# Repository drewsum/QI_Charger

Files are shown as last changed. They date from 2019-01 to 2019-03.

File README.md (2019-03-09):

# QI_Charger

A DIY QI Wireless Phone Charger with Digital Monitoring, OLED Display, and USB Virtual COM Port

Made with KiCad 5.0.2

Requires drewsum's 'KiCad_Custom_Libraries' git repository for custom symbols and footprints

Microcontroller U503 is programmed via header J401 using PIC KIT 3, with firmware located at sfw/U503_Firmware/QI_Monitor.X

Built with Microchip compiler XC8 V1.45, IDE MPLAB V5.15

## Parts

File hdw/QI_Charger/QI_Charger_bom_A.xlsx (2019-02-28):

References | Value | Quantity Per PCB | Digi-Key PN
C201 C204 C205 C303 C304 C401 C402 C501 C502 C503 C506 C601 C602 C609 C613 C701 C807 C808 C901 C902 C1001 C1002 C1003 C1004 C1005 C1007 C1008 C1011 C1101 C1102 C1103 C1104 C1105 C1106 C1107 C1108 C1109 C1201 C1202 C1203 C1301 C1309 C1311 C1314 C1316 C1401 C1403 C1404 | 0.1uF | 48 | 311-1344-1-ND
C209 C1323 | 100uF | 2 | 718-1102-1-ND
C202 C206 C302 C305 C504 C507 C603 C604 C607 C608 C610 C612 C614 C616 C702 C801 C802 C805 C806 C1302 C1310 C1312 C1319 C1402 | 10nF | 24 | 1276-1921-1-ND
C301 | 10uF | 1 | 1276-7031-1-ND
C203 C207 C208 C306 C505 C508 C605 C606 C611 C615 C703 C803 C804 C1303 C1304 C1306 C1317 C1405 | 1nF | 18 | 1276-1018-1-ND
C704 | 1uF | 1 | 490-1695-1-ND
C1305 | 2.2pF | 1 | 1276-1281-1-ND
C1318 C1322 | 22nF | 2 | 399-1280-1-ND
C307 C308 C1307 C1308 | 22uF | 4 | 1276-3148-1-ND
C1006 | 4.7uF | 1 | 1276-2972-1-ND
C1009 C1010 | 47pF | 2 | 478-1171-1-ND
C1313 C1315 | 6.8nF | 2 | 399-9121-1-ND
C1320 C1321 | 82nF | 2 | 478-10362-1-ND
D201 | 24V | 1 | SMAJ24CALFCT-ND
D1001 D1105 D1107 D1108 D1109 | Green | 5 | 160-1446-1-ND
D1301 | MBR0530 | 1 | MBR0530T1GOSCT-ND
D1101 D1102 D1103 D1104 D1106 | Red | 5 | 160-1447-1-ND
D1002 | Yellow | 1 | 160-1448-1-ND
DOC701 | 0x3C | 1
DOC1202 | 0x4C | 1
DOC1201 | 0x4D | 1
DOC1203 | 0x4F | 1
DOC1001 | COM_Port_Settings | 1
DOC501 | Master | 1
J201 | +12V IN | 1 | CP-202BH-ND
J1301 J1302 | PAD | 2 | 732-3214-ND
J401 | PICKIT3 | 1
J1001 | USB_B_Mini | 1 | 732-2109-1-ND
L301 | 2.2u | 1 | 541-1236-1-ND
L1301 | 6.3uH | 1 | 732-5284-ND
L501 L502 L1001 L1002 | 600R 0.5A | 4 | 732-2389-1-ND
MK1501 MK1502 MK1507 MK1508 MK1511 MK1512 MK1515 MK1516 | #4-40 Screw | 8 | 36-9900-ND
MK1503 MK1504 MK1505 MK1506 MK1509 MK1510 MK1513 MK1514 | #4-40 Standoff | 8 | 36-1892-ND
Q401 | BSS214NW | 1 | BSS214NWH6327XTSA1CT-ND
Q201 Q202 | IPC100N04S51R7ATMA1 | 2 | IPC100N04S51R7ATMA1CT-ND
R405 R501 R502 R701 R702 R803 R804 R1201 R1202 R1203 R1204 R1205 R1206 | 0 | 13 | 311-0.0GRCT-ND
R209 R1303 | 0.02 | 2 | P16010CT-ND
R1312 R1313 | 1 | 2 | 311-1.00HRCT-ND
R1315 | 1.8k | 1 | CR0603-FX-1801ELFCT-ND
R205 R206 R401 | 10 | 3 | YAG3351CT-ND
R303 R306 | 10.5k | 2 | 311-10.5KHRCT-ND
R403 | 100 | 1 | A106047CT-ND
R204 R302 R305 R1308 R1404 | 100k | 5 | A106046CT-ND
R207 R301 R308 R402 R404 R503 R504 R505 R506 R601 R602 R606 R703 R704 R901 R902 R903 R904 R1001 R1005 R1101 R1102 R1103 R1107 R1108 R1111 R1114 R1207 R1208 R1209 R1210 R1211 R1212 R1213 R1214 R1306 R1401 R1402 R1405 R1406 R1407 | 10k | 41 | RMCF0603FT10K0CT-ND
R1309 | 130k | 1 | 311-130KHRCT-ND
R1311 R1314 R1316 | 15k | 3 | 311-15.0KHRCT-ND
R1310 | 1M | 1 | 311-1.00MHRCT-ND
R406 R1006 R1009 R1104 R1105 R1106 R1109 R1110 R1112 R1113 R1115 R1116 R1403 | 1k | 13 | RMCF0603FT1K00CT-ND
R203 | 243k | 1 | 311-243KHRCT-ND
R304 R1304 | 249k | 2 | RMCF0603FT249KCT-ND
R1007 R1008 | 27 | 2 | RMCF0603FT27R0CT-ND
R1317 | 27k | 1 | RMCF0603FT27K0CT-ND
R307 | 2k | 1 | 311-2.00KHRCT-ND
R1301 R1302 | 390k | 2 | 311-390KHRCT-ND
R1004 | 40.2k | 1 | 311-40.2KHRCT-ND
R1307 | 43k | 1 | 311-43.0KHRCT-ND
R1305 | 47k | 1 | 311-47.0KHRCT-ND
R1002 | 487k | 1 | 311-487KHRCT-ND
R603 R604 R605 R608 R801 R802 | 499 | 6 | P499HCT-ND
R210 | 499k | 1 | RMCF0603FT499KCT-ND
R208 R607 | 5.1k | 2 | YAG3621CT-ND
R201 | 6.04M | 1 | 541-6.04MHCT-ND
R201 | 6.04k | 1 | RMCF0603FT6K04CT-ND
R202 | 86.6k | 1 | 311-86.6KHRCT-ND
SW801 SW802 | Cap_Touch | 2
SW401 | MRST | 1
TH1301 | 100k | 1 | P10555CT-ND
U1003 U1101 U1104 U1106 U1107 U1108 U1109 1103 | 74LVC1G06 | 8 | 296-8484-1-ND
U1102 U1105 | 74LVC1G07 | 2 | 296-8486-1-ND
U1401 U1402 | 74LVC1G14 | 2 | 296-11608-1-ND
U302 U501 U502 U1403 | 74LVC1G17 | 4 | 296-11934-1-ND
U801 U802 | AT42QT1010-TSHR | 2 | AT42QT1010-TSHRCT-ND
U1002 | FT234XD | 1 | 768-1178-1-ND
U202 U1301 | INA138 | 2 | INA138NACT-ND
U901 | ISO7321C | 1 | 296-42102-1-ND
U1201 U1202 U1203 | LM73-1 | 3 | LM73CIMK-1/NOPBCT-ND
U1001 | LT6700-1-S6 | 1 | LT6700CS6-1#TRMPBFCT-ND
U201 | LTC4365DDB | 1 | LTC4365IDDB#TRMPBFCT-ND
U1302 | NXQ1TXH5_101J | 1 | 568-12937-1-ND
U601 U602 U603 U604 | OPA340NA | 4 | 296-26275-1-ND
U503 | PIC18F27K40T-I_ML | 1 | PIC18F27K40T-I/MLCT-ND
U701 | SSD1306 | 1
U1004 | TPD3S014DBVR | 1 | 296-38835-1-ND
U301 | TPS62130 | 1 | 296-37878-1-ND
Y1301 | 32.768kHz | 1 | G83270021CT-ND

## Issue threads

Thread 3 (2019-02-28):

I2C OLED

drewsum, 2019-02-28:
Copy I2C OLED code from the AC power meter project and change things so that it will integrate correctly. Add code to the cap_touch_buttons module to control what's on the screen by pressing the buttons

Closed 2019-03-09.

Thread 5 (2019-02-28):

CCP Input Capture for POS5 and QI switching frequencies

drewsum, 2019-02-28:
Add CCP code to be able to measure the POS5 and QI switching frequencies.

drewsum, 2019-02-28:
Also need to solder on the appropriate divider resistor onto the board to connect QI_SW to the digital signal buffer. Might need to recalculate what this resistor value should be.

Closed 2019-03-09.

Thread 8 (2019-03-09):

Add Charge Time Variable, OLED Screen, Serial Commands

drewsum, 2019-03-09:
Add functionality to keep track of how long a phone has been charging. This will involve integrating nxw_charge_state, OLED, USB UART, and heartbeat timer together.

Closed 2019-03-10.

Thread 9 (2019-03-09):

Fix error charge state detection bug

drewsum, 2019-03-09:
Right now, nxq_charge_state can detect idle, charge, and charging, but error detection isn't working. Look into this.

Closed 2019-03-10.

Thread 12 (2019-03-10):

Debug random QI fault issues

drewsum, 2019-03-10:
The QI converter randomly enters a fault. I have a feeling this has something to do with the placement of the QI NTC on the PCB. Find a way to keep this from happening as often. Will probably be a hardware change.

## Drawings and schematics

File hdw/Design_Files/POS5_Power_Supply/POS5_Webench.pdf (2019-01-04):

## WEBENCH ® Design Report

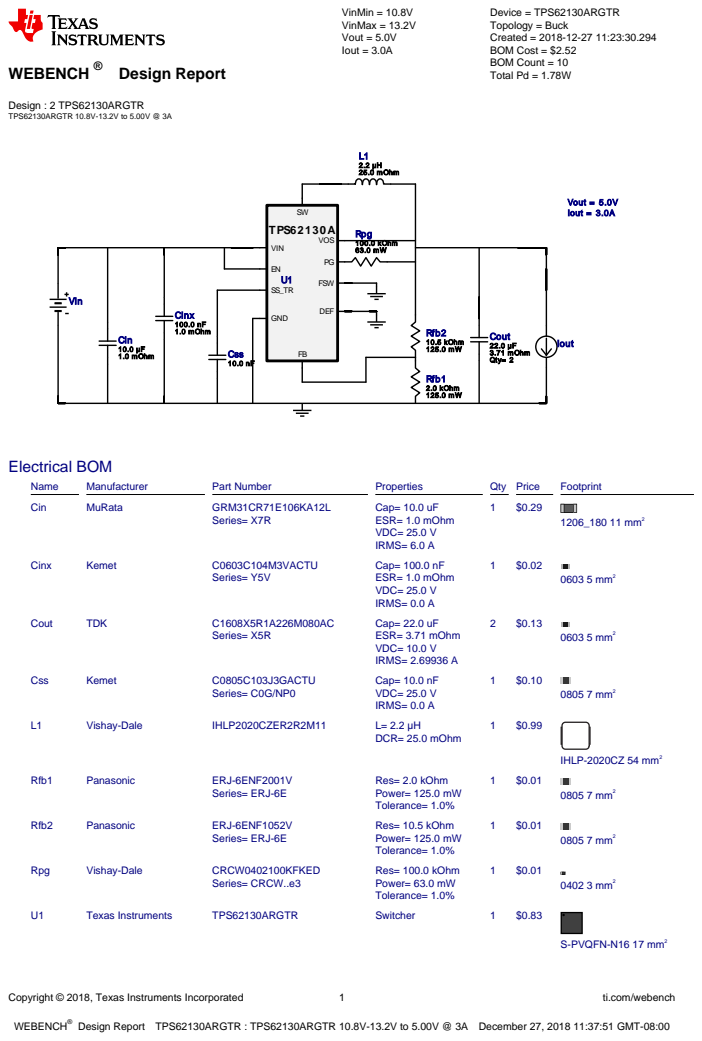
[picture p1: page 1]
Copyright © 2018, Texas Instruments Incorporated; ti.com/webench; WEBENCH®; Design : 2 TPS62130ARGTR TPS62130ARGTR 10.8V-13.2V to 5.00V @ 3A; VinMin = 10.8V VinMax = 13.2V Vout = 5.0V Iout = 3.0A; Device = TPS62130ARGTR Topology = Buck Created = 2018-12-27 11:23:30.294 BOM Cost = $2.52 BOM Count = 10 Total Pd = 1.78W; Cin 10.0 µF 1.0 mOhm; Cout 22.0 µF 3.71 mOhm Qty= 2 Css 10.0 nF; L1 2.2 µH 25.0 mOhm; Rfb1 2.0 kOhm 125.0 mW; Rfb2 10.5 kOhm 125.0 mW; Rpg 100.0 kOhm 63.0 mW; TPS62130A; GND; DEF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

Design Report TPS62130ARGTR : TPS62130ARGTR 10.8V-13.2V to 5.00V @ 3A December 27, 2018 11:37:51 GMT-08:00

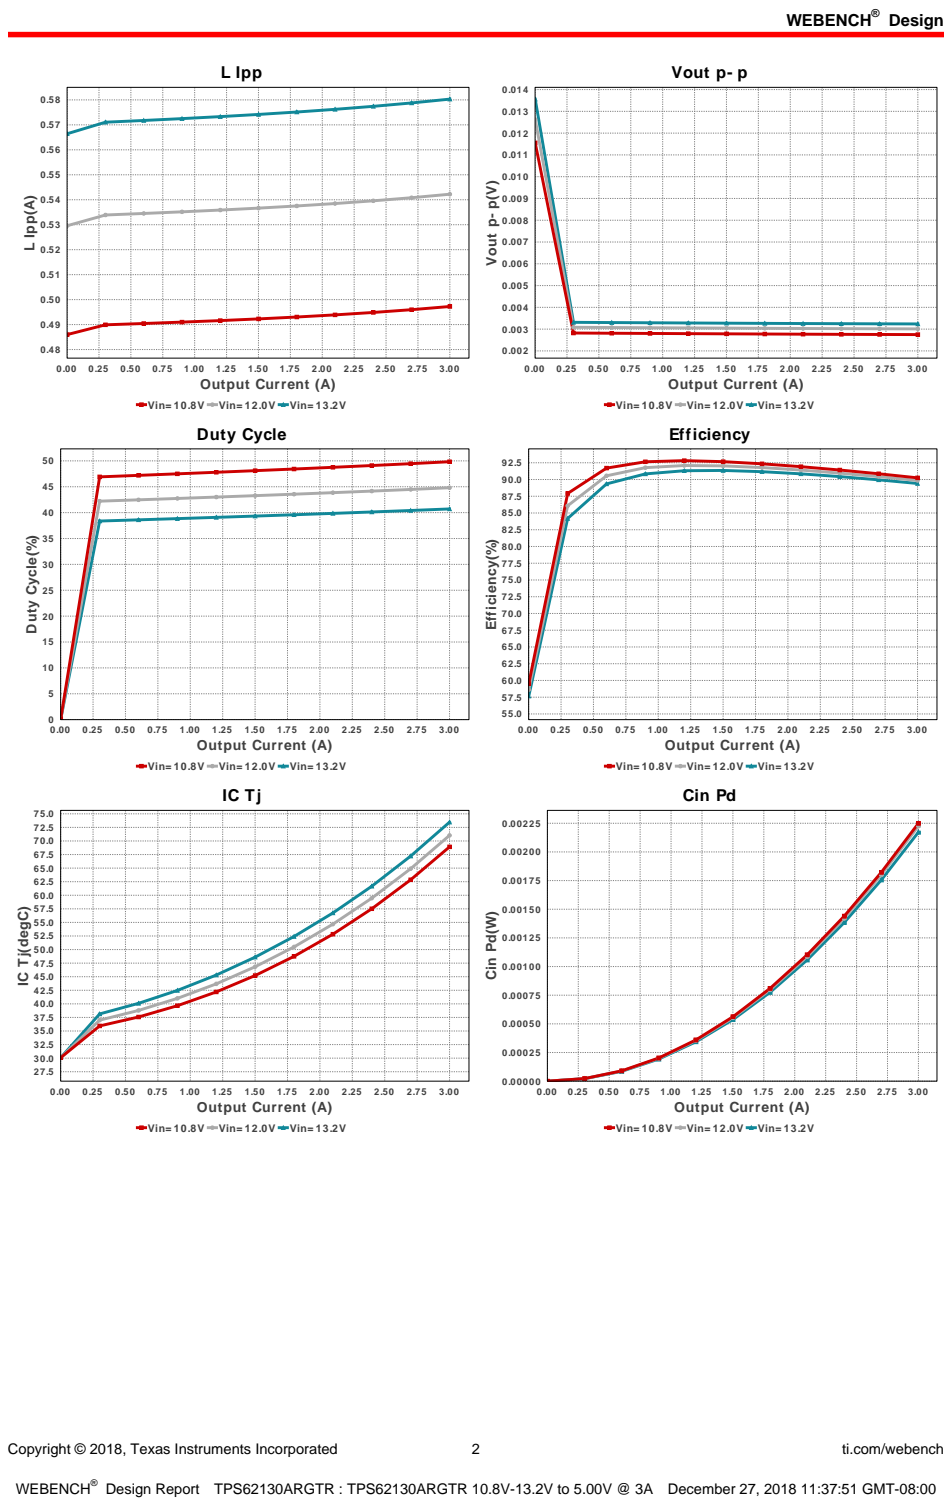
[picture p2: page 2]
Design; Copyright © 2018, Texas Instruments Incorporated; ti.com/webench; L Ipp; 0.00 0.25 0.50 0.75 1.00 1.25 1.50 1.75 2.00 2.25 2.50 2.75 3.00 Output Current (A); L Ipp(A); Vout p- p; Vout p- p(V); Duty Cycle(%); Efficiency(%); Cin Pd; Cin Pd(W)

Vin= 10.8V Vin= 12.0V Vin= 13.2V
Duty Cycle

Efficiency

IC Tj(degC)

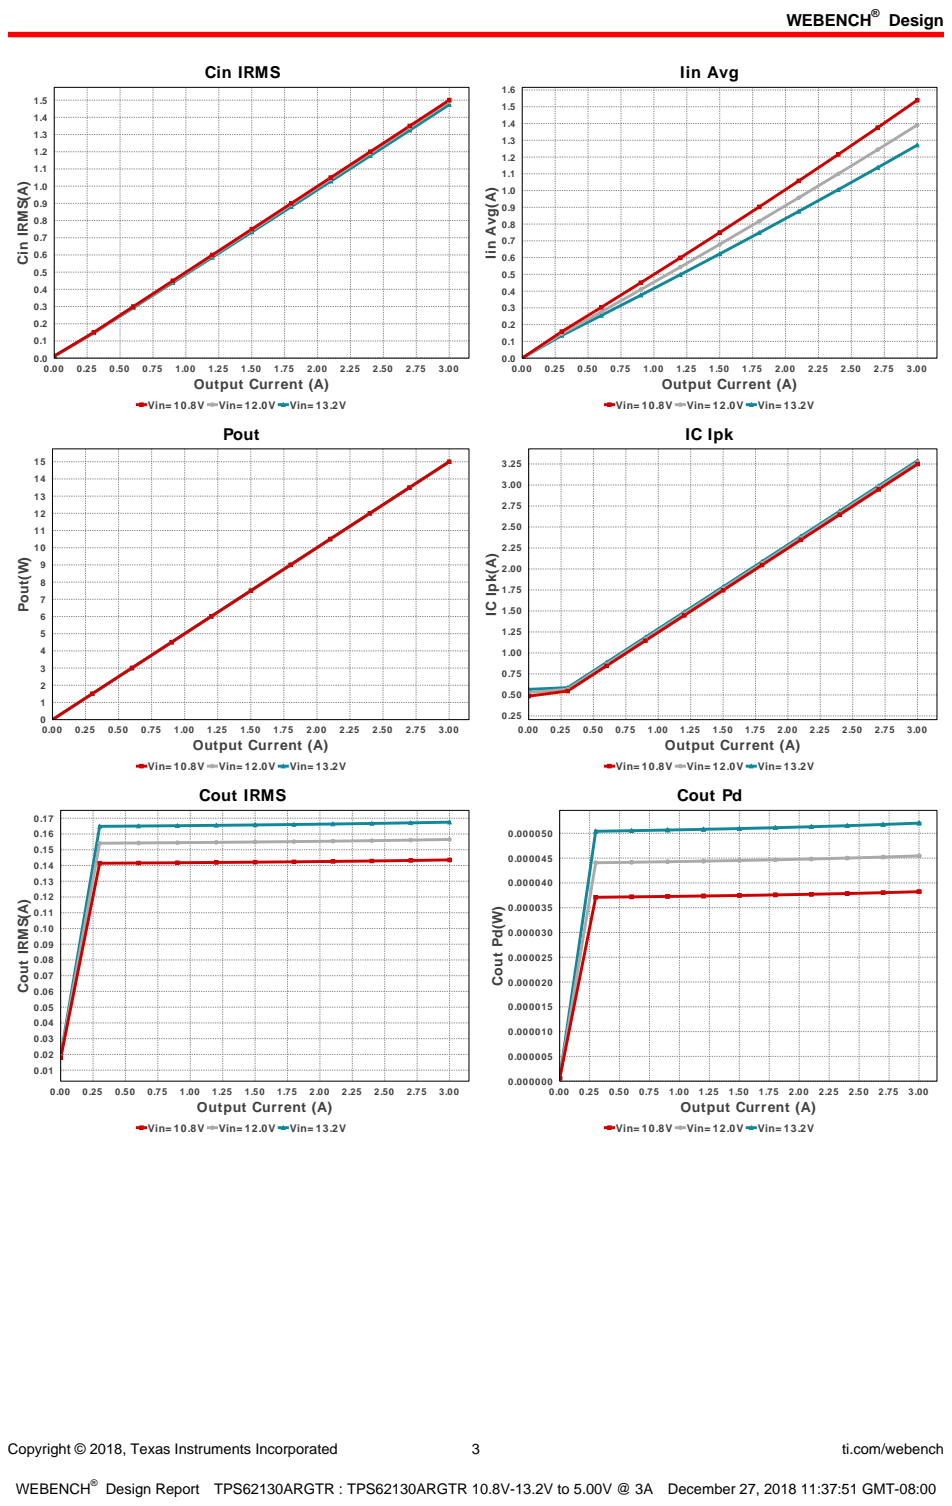
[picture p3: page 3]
Copyright © 2018, Texas Instruments Incorporated; ti.com/webench; Cin IRMS; 0.00 0.25 0.50 0.75 1.00 1.25 1.50 1.75 2.00 2.25 2.50 2.75 3.00 Output Current (A); Cin IRMS(A); Iin Avg; Iin Avg(A); Pout; Pout(W); IC Ipk; IC Ipk(A); Cout IRMS(A); Cout Pd; Cout Pd(W)

Vin= 10.8V Vin= 12.0V Vin= 13.2V

Cout IRMS

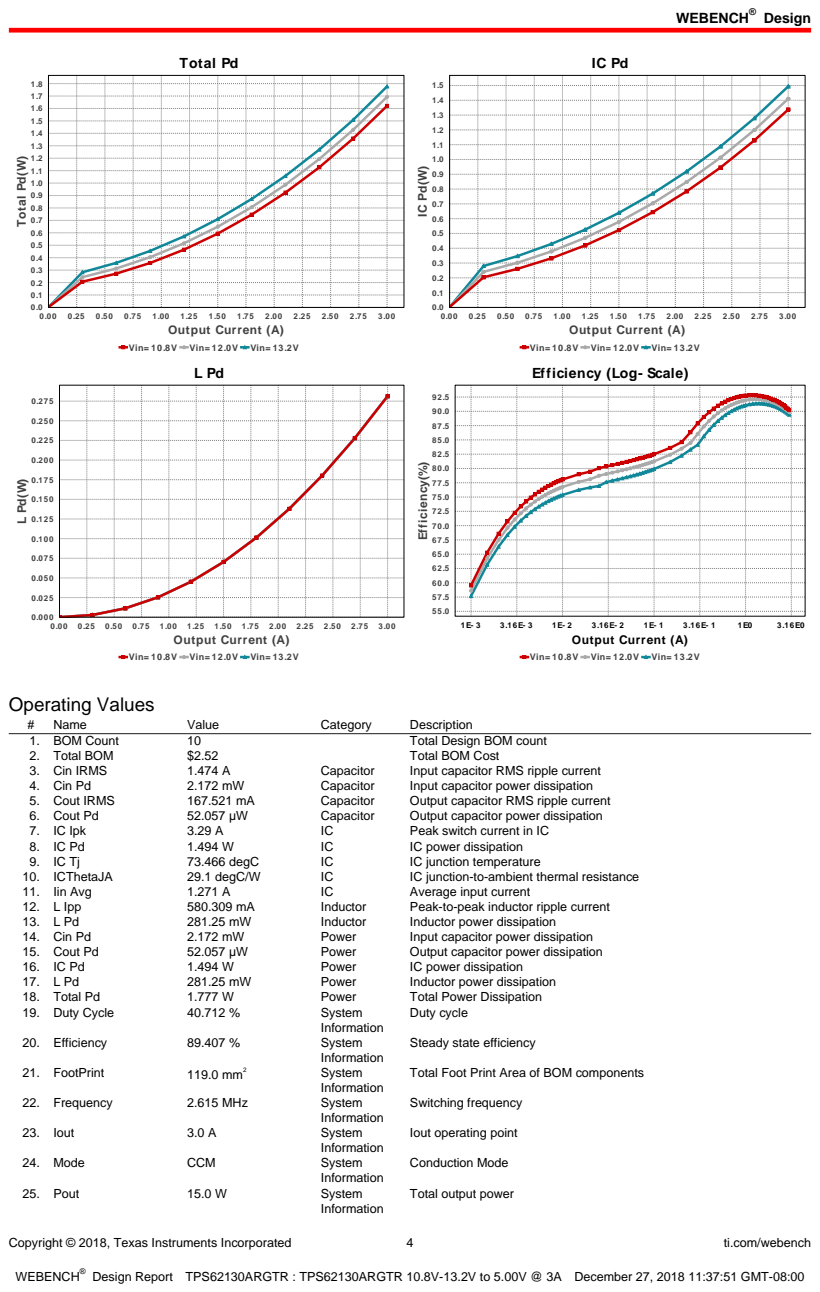
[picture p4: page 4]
Copyright © 2018, Texas Instruments Incorporated; ti.com/webench; Total Pd; 0.00 0.25 0.50 0.75 1.00 1.25 1.50 1.75 2.00 2.25 2.50 2.75 3.00 Output Current (A); Total Pd(W); 3.16E0 Output Current (A); Efficiency(%); Operating Values; Name; Value; Category; Description; 1. BOM Count; Total Design BOM count; 2. Total BOM; Total BOM Cost; 3. Cin IRMS; Capacitor; Input capacitor RMS ripple current; 4. Cin Pd; Input capacitor power dissipation; 5. Cout IRMS; Output capacitor RMS ripple current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

Vin= 10.8V Vin= 12.0V Vin= 13.2V

Efficiency (Log- Scale)

Steady state efficiency

Total Foot Print Area of BOM components

Iout operating point

Total output power

Copyright © 2018, Texas Instruments Incorporated | 5 | ti.com/webench
# | Name | Value | Category | Description

26. Vin | 13.2 V | System
| | | Information | Vin operating point
27. Vout | 5.0 V | System
| | | Information | Operational Output Voltage
28. Vout Actual | 5.0 V | System
| | | Information | Vout Actual calculated based on selected voltage divider resistors
29. Vout Tolerance | 3.528 % | System
| | | Information | Vout Tolerance based on IC Tolerance (no load) and voltage divider resistors if applicable
30. Vout p-p | 3.238 mV | System
| | | Information | Peak-to-peak output ripple voltage

## Design Inputs

Name | Value | Description
Iout | 3.0 | Maximum Output Current
VinMax | 13.2 | Maximum input voltage
VinMin | 10.8 | Minimum input voltage
Vout | 5.0 | Output Voltage
| base_pn | | TPS62130A | Base Product Number
source | DC | Input Source Type
Ta | 30.0 | Ambient temperature


Copyright © 2018, Texas Instruments Incorporated | 6 | ti.com/webench

## Assembly

## Component Testing

Some published data on components in datasheets such as Capacitor ESR and Inductor DC resistance is based on conservative values that will guarantee that the components always exceed the specification. For design purposes it is usually better to work with typical values. Since this data is not always available it is a good practice to measure the Capacitance and ESR values of Cin and Cout, and the inductance and DC resistance of L1 before assembly of the board. Any large discrepancies in values should be electrically simulated in WEBENCH to check for instabilities and thermally simulated in WebTHERM to make sure critical temperatures are not exceeded.

## Soldering Component to Board

If board assembly is done in house it is best to tack down one terminal of a component on the board then solder the other terminal. For surface mount parts with large tabs, such as the DPAK, the tab on the back of the package should be pre-tinned with solder, then tacked into place by one of the pins. To solder the tab town to the board place the iron down on the board while resting against the tab, heating both surfaces simultaneously. Apply light pressure to the top of the plastic case until the solder flows around the part and the part is flush with the PCB. If the solder is not flowing around the board you may need a higher wattage iron (generally 25W to 30W is enough).
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

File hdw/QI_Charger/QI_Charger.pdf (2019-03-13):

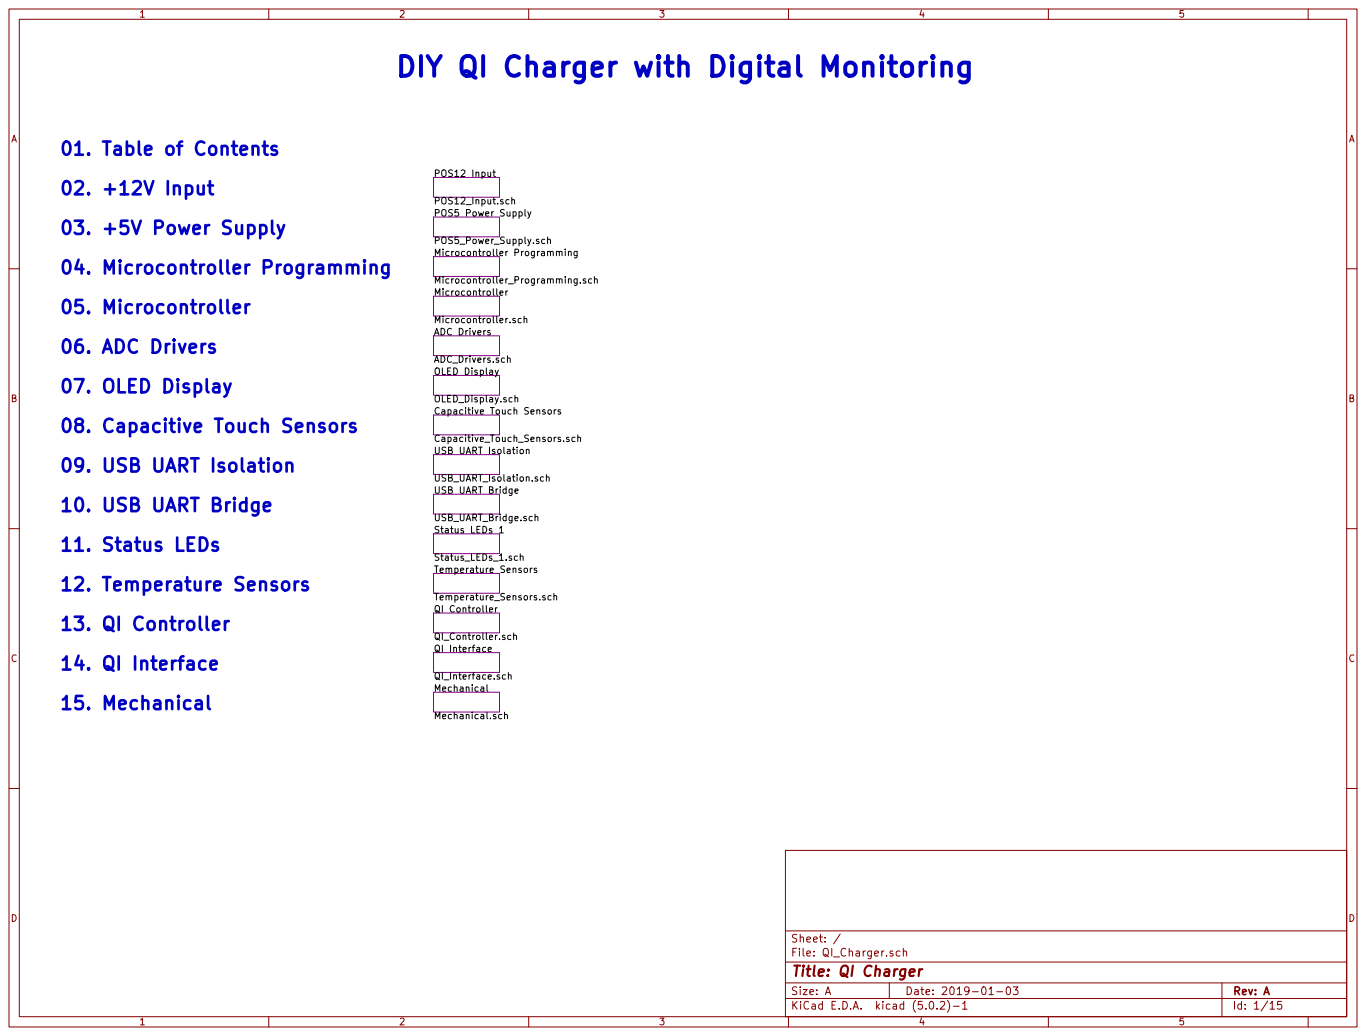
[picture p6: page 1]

DIY QI Charger with Digital Monitoring

Temperature_Sensors.sch QI Controller QI_Controller.sch QI Interface QI_Interface.sch 01. Table of Contents
02. +12V Input
03. +5V Power Supply
04. Microcontroller Programming
05. Microcontroller
06. ADC Drivers
07. OLED Display
08. Capacitive Touch Sensors
09. USB UART Isolation
10. USB UART Bridge
11. Status LEDs
12. Temperature Sensors
13. QI Controller
14. QI Interface

Microcontroller_Programming.sch Microcontroller Microcontroller.sch ADC Drivers ADC_Drivers.sch OLED Display

Capacitive_Touch_Sensors.sch USB UART Isolation USB_UART_Isolation.sch USB UART Bridge

USB_UART_Bridge.sch Status LEDs 1 Status_LEDs_1.sch Temperature Sensors

Mechanical Mechanical.sch 15. Mechanical

File: QI_Charger.sch Sheet: /
Id: 1/15 Title: QI Charger

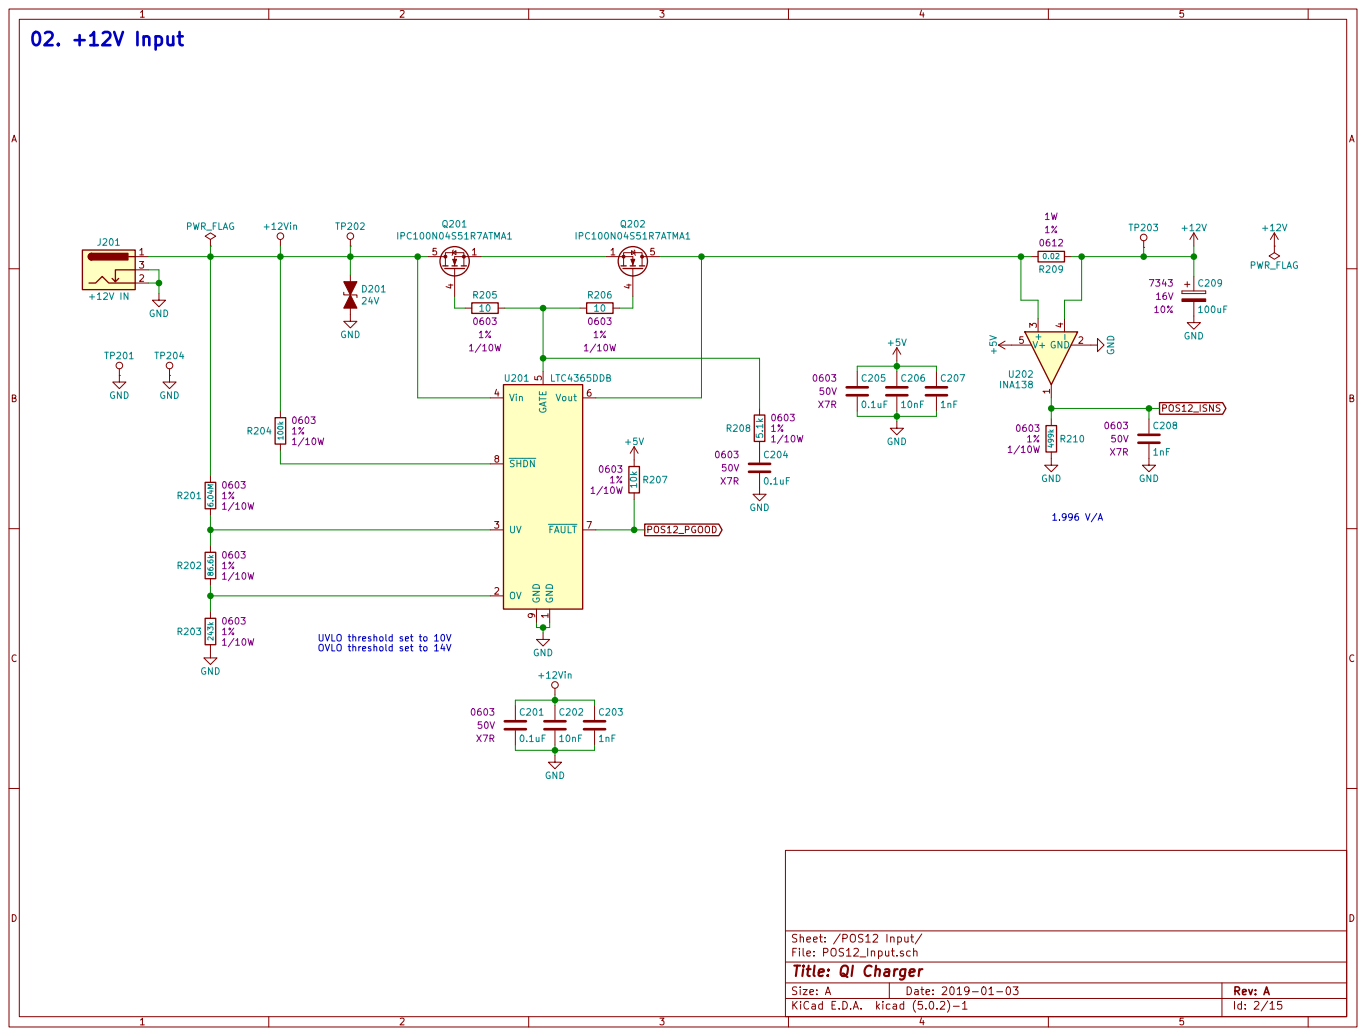
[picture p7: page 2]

5 Vout 6 FAULT 7 SHDN 8 GND

1 OV 2 UV 3 Vin 4 GATE

File: POS12_Input.sch
Id: 2/15 Title: QI Charger

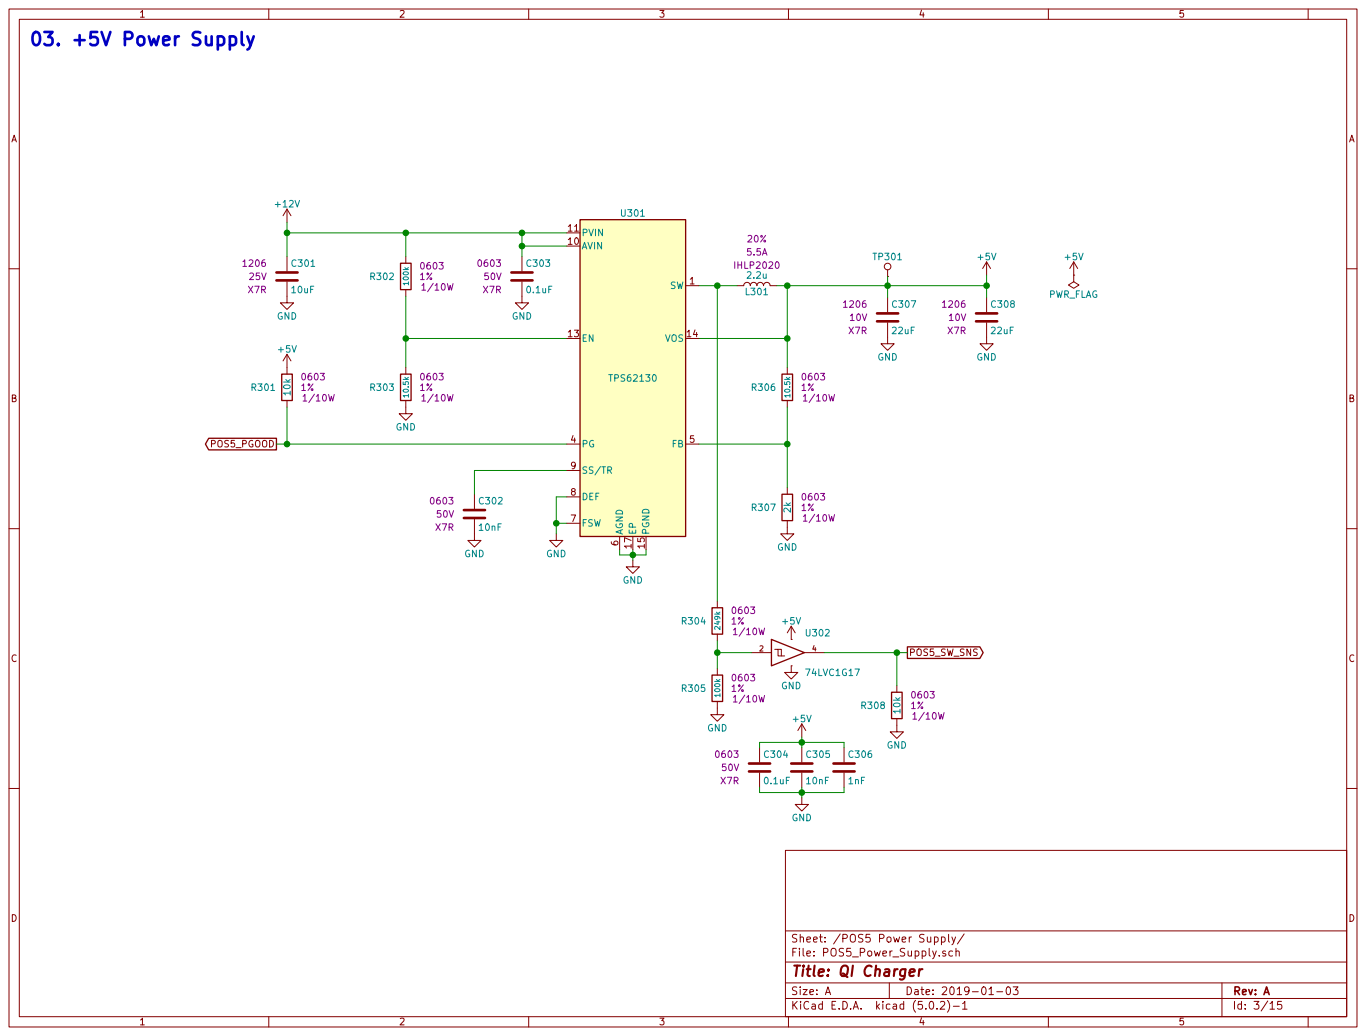
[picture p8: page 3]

6 FSW 7 DEF 8 SS/TR 9 U301 TPS62130 +5V

Sheet: /POS5 Power Supply/
File: POS5_Power_Supply.sch
Id: 3/15 Title: QI Charger

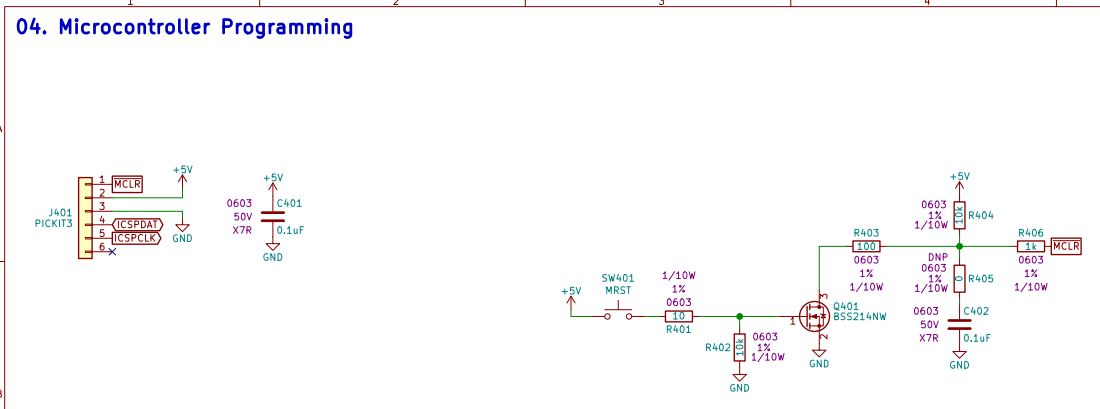
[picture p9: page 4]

Sheet: /Microcontroller Programming/
File: Microcontroller_Programming.sch
Id: 4/15 Title: QI Charger

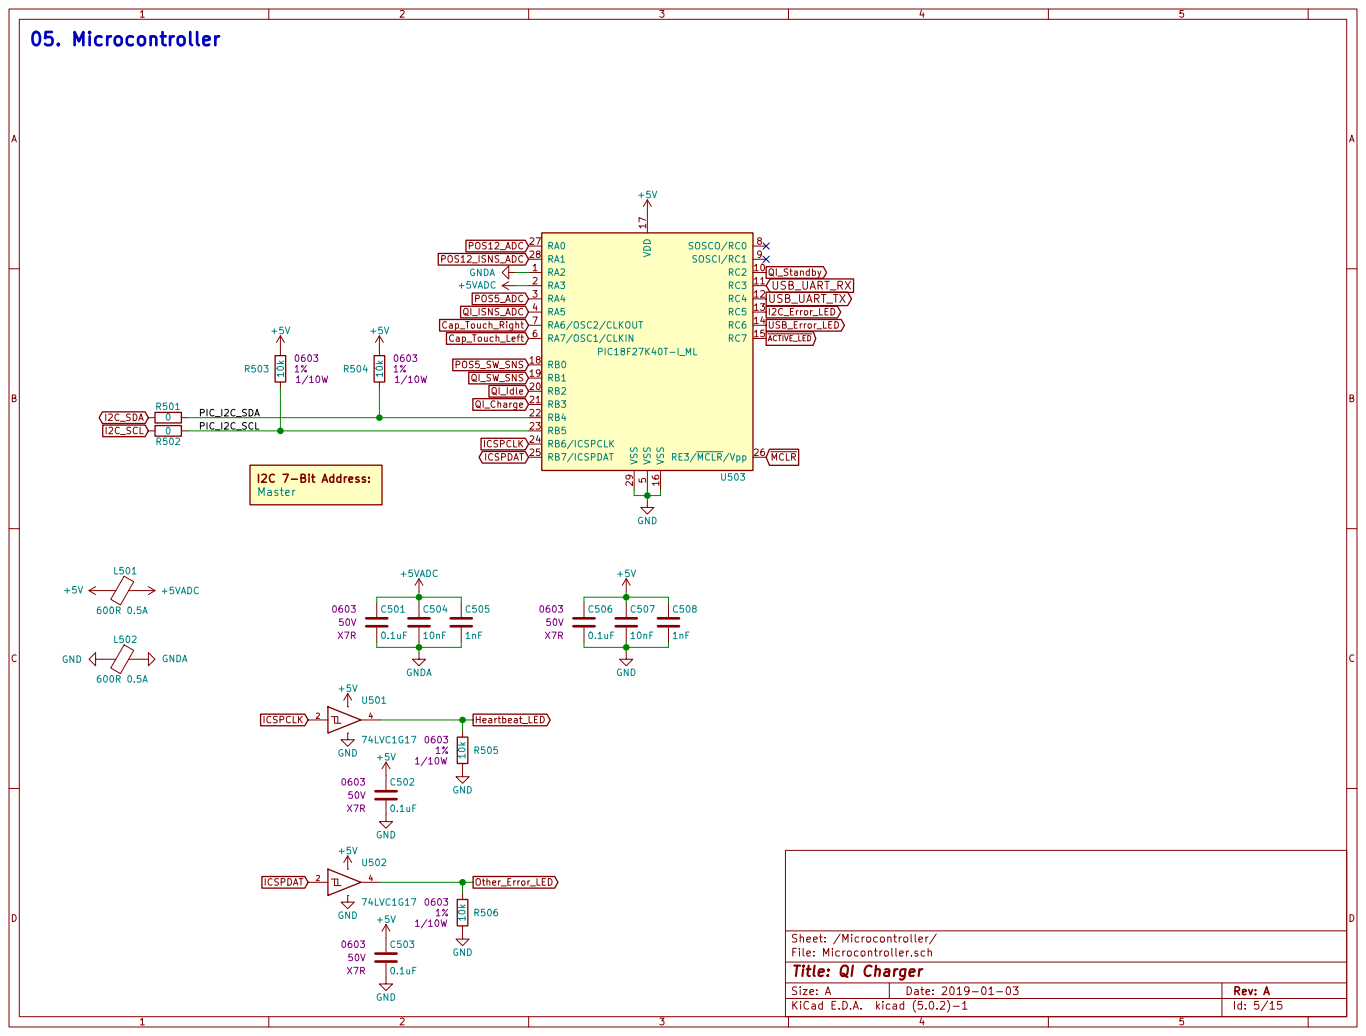
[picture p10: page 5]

I2C 7-Bit Address: Master 05. Microcontroller

5 RA7/OSC1/CLKIN 6 RA6/OSC2/CLKOUT 7 SOSCO/RC0 8 SOSCI/RC1 9 U503 PIC18F27K40T-I_ML GND

Id: 5/15 Title: QI Charger File: Microcontroller.sch Sheet: /Microcontroller/

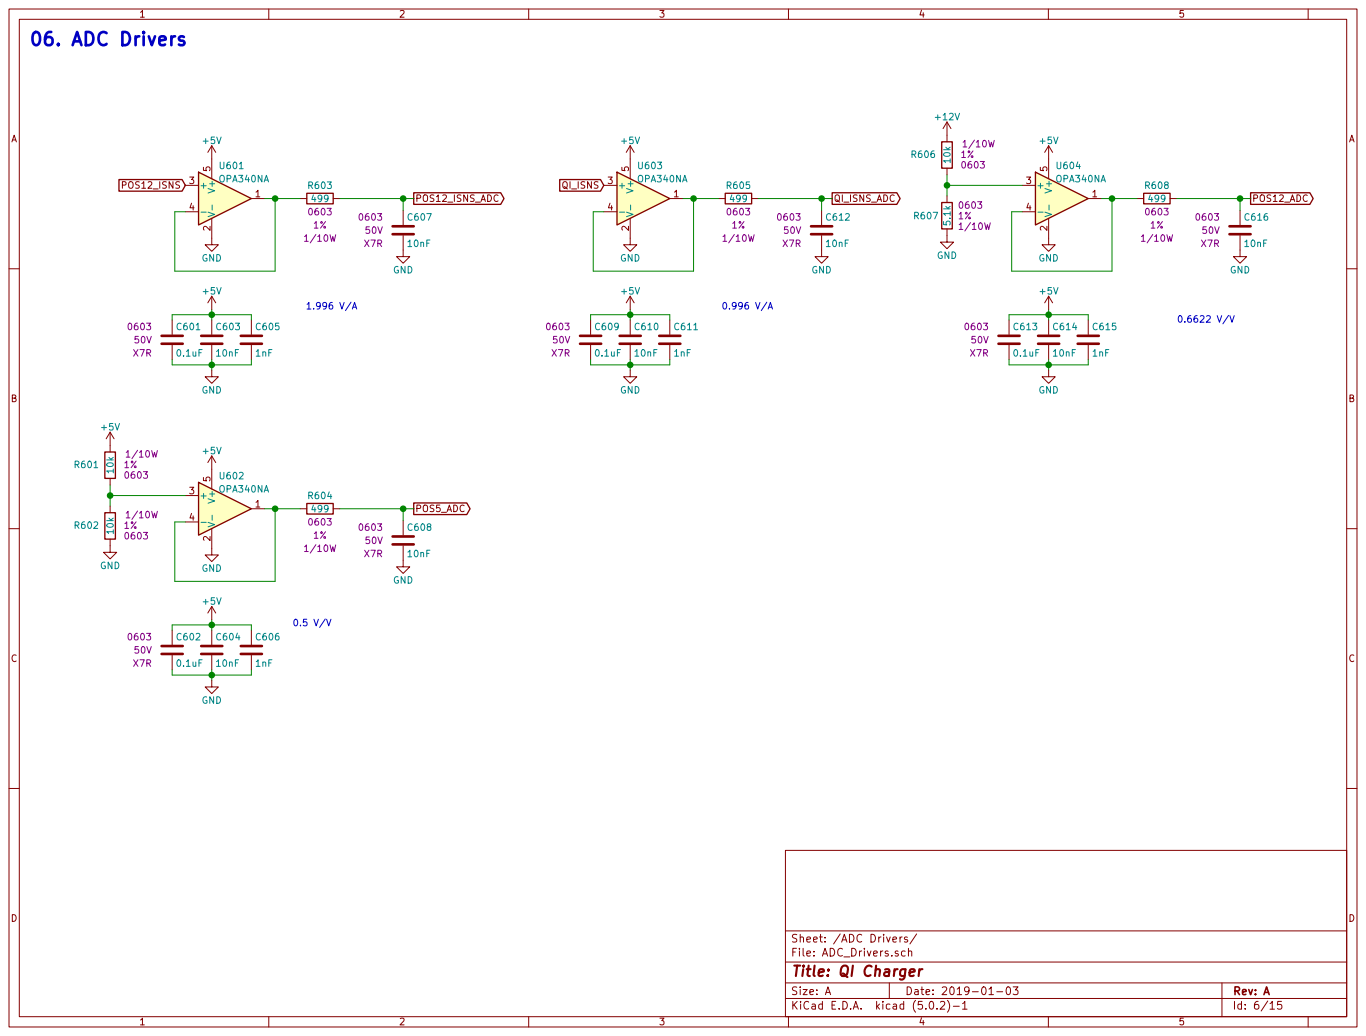
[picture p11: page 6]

Id: 6/15 Title: QI Charger

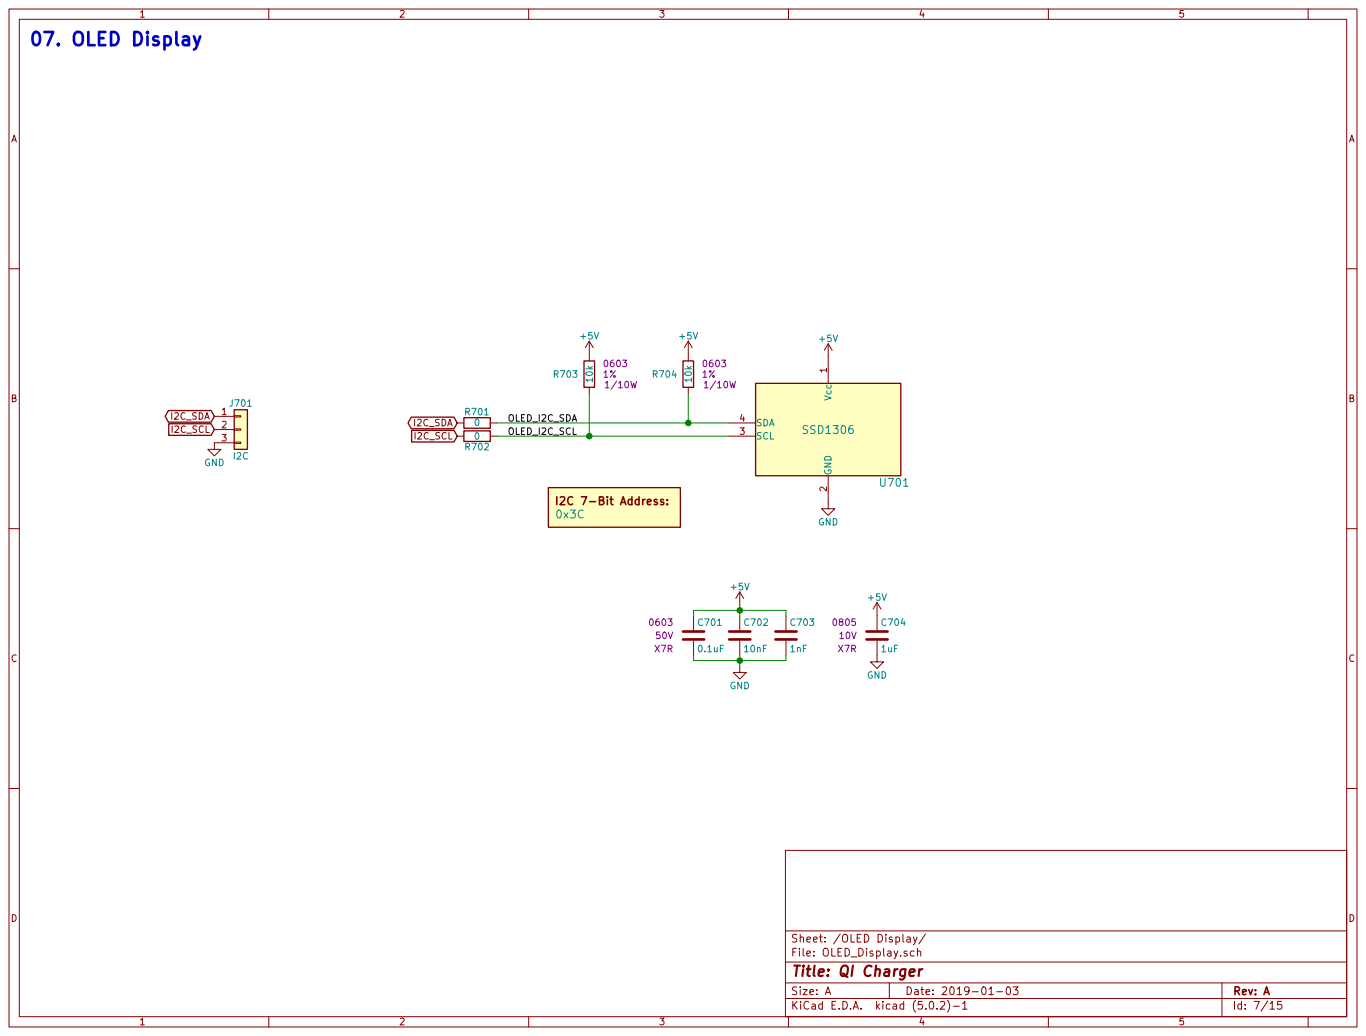
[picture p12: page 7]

Sheet: /OLED Display/ Vcc 1 GND

File: OLED_Display.sch
Id: 7/15 Title: QI Charger


Sheet: /Capacitive Touch Sensors/
File: Capacitive_Touch_Sensors.sch
Id: 8/15 Title: QI Charger


Id: 9/15 Title: QI Charger


USB Virtual COM Port Settings:

Sheet: /USB UART Bridge/
File: USB_UART_Bridge.sch
Id: 10/15 Title: QI Charger


File: Status_LEDs_1.sch Sheet: /Status LEDs 1/
Id: 11/15 Title: QI Charger


Placed near QI Controller Placed near +5V Power supply

Placed away from power dissipating components

Sheet: /Temperature Sensors/
File: Temperature_Sensors.sch
Id: 12/15 Title: QI Charger


File: QI_Controller.sch
Id: 13/15 Title: QI Charger


Sheet: /QI Interface/
File: QI_Interface.sch
Id: 14/15 Title: QI Charger


Id: 15/15 Title: QI Charger File: Mechanical.sch Sheet: /Mechanical/

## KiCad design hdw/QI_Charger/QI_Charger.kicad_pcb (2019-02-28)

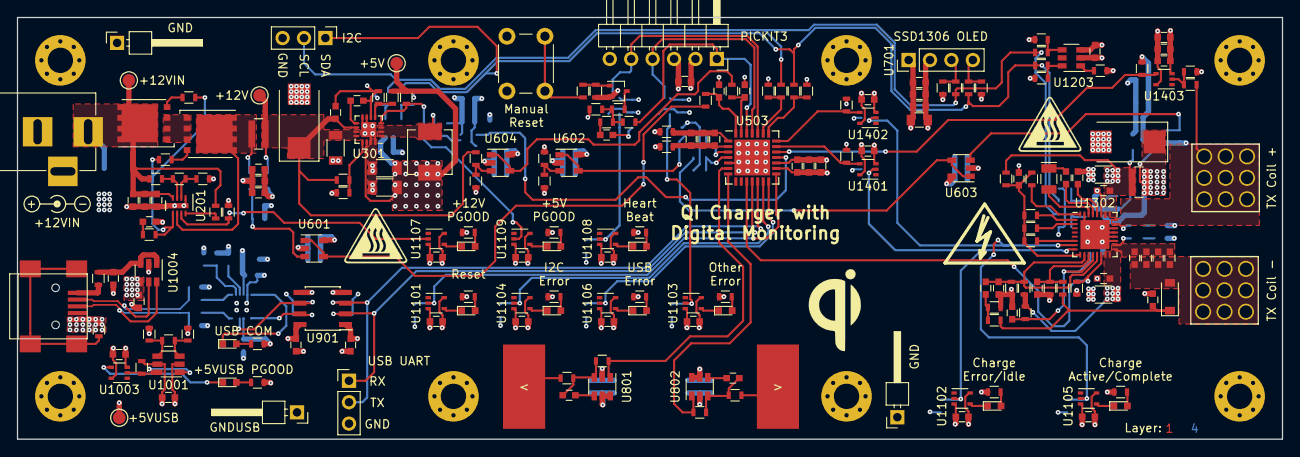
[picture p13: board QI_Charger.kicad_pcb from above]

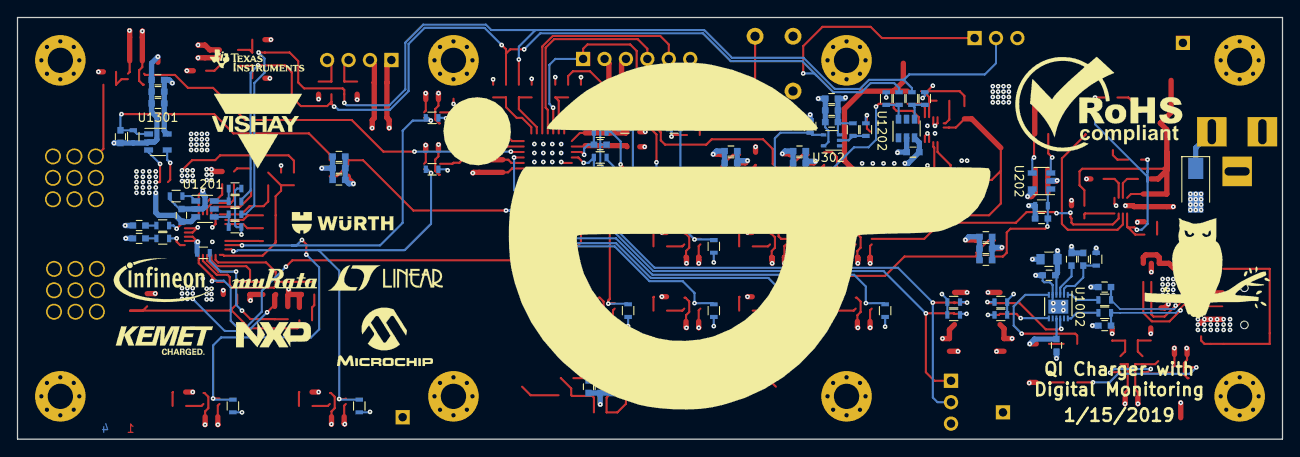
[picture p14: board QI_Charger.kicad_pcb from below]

Board: 4 copper layers, 150.0 x 50.0 mm, 305 parts (87 on the bottom side), 137 nets.

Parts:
C201, C204, C205, C303, C304, C401, C402, C501, C502, C503, C506, C601, C602, C609, C613, C701, C807, C808, C901, C902, C1001, C1002, C1003, C1004, C1005, C1007, C1008, C1011, C1101, C1102, C1103, C1104, C1105, C1106, C1107, C1108, C1109, C1201, C1202, C1203, C1301, C1309, C1311, C1314, C1316, C1401, C1403, C1404: 0.1uF; C_0603
C202, C206, C302, C305, C504, C507, C603, C604, C607, C608, C610, C612, C614, C616, C702, C801, C802, C805, C806, C1302, C1310, C1312, C1319, C1402: 10nF; C_0603
C203, C207, C208, C306, C505, C508, C605, C606, C611, C615, C703, C803, C804, C1303, C1304, C1306, C1317, C1405: 1nF; C_0603
C209, C1323: 100uF; CP_Tantalum_Case-X_EIA-7343-43_Reflow
C301: 10uF; C_1206
C307, C308, C1307, C1308: 22uF; C_1206
C704: 1uF; C_0805
C1006: 4.7uF; C_0805
C1009, C1010: 47pF; C_0603
C1305: 2.2pF; C_0603
C1313, C1315: 6.8nF; C_0603
C1318, C1322: 22nF; C_0603
C1320, C1321: 82nF; C_0603
D201: 24V; D_SMA
D1001, D1105, D1107, D1108, D1109: Green; LED_0603
D1002: Yellow; LED_0603
D1101, D1102, D1103, D1104, D1106: Red; LED_0603
D1301: MBR0530; D_SOD-123
H1501, H1502, H1503, H1504, H1505, H1506, H1507, H1508: 3mm Mounting Hole; MountingHole_3mm_Pad_Via
J201: +12V IN; BARREL_JACK
J401: PICKIT3; PICKIT3_Header
J701: I2C; Pin_Header_Straight_1x03_Pitch2.54mm
J901: UART; Pin_Header_Straight_1x03_Pitch2.54mm
J1001: USB_B_Mini; USB_Mini-B
J1301, J1302: PAD; Wuerth_7461096_M4_Shank_9pos
L301: 2.2u; L_Vishay_IHLP-2020
L501, L502, L1001, L1002: 600R 0.5A; L_0603
Q201, Q202: IPC100N04S51R7ATMA1; TDSON-8-1
Q401: BSS214NW; SOT-323_SC-70
R201: 6.04M; R_0603
R202: 86.6k; R_0603
R203: 243k; R_0603
R204, R302, R305, R1308, R1404: 100k; R_0603
R205, R206, R401: 10; R_0603
R207, R301, R308, R402, R404, R503, R504, R505, R506, R601, R602, R606, R703, R704, R901, R902, R903, R904, R1001, R1005, R1101, R1102, R1103, R1107, R1108, R1111, R1114, R1207, R1208, R1209, R1210, R1211, R1212, R1213, R1214, R1306, R1401, R1402, R1405, R1406, R1407: 10k; R_0603
R208, R607: 5.1k; R_0603
R209, R1303: 0.02; R_0612
R210: 499k; R_0603
R303, R306: 10.5k; R_0603
R304, R1304: 249k; R_0603
R307: 2k; R_0603
R403: 100; R_0603
R405, R501, R502, R701, R702, R803, R804, R1201, R1202, R1203, R1204, R1205, R1206: 0; R_0603
R406, R1006, R1009, R1104, R1105, R1106, R1109, R1110, R1112, R1113, R1115, R1116, R1403: 1k; R_0603
R603, R604, R605, R608, R801, R802: 499; R_0603
R1002: 487k; R_0603
R1003: 6.04k; R_0603
R1004: 40.2k; R_0603
R1007, R1008: 27; R_0603
R1301, R1302: 390k; R_0603
R1305: 47k; R_0603
R1307: 43k; R_0603
R1309: 130k; R_0603
R1310: 1M; R_0603
R1311, R1314, R1316: 15k; R_0603
R1312, R1313: 1; R_0603
R1315: 1.8k; R_0603
R1317: 27k; R_0603
SW401: MRST; SW_PUSH_6mm
SW801, SW802: Cap_Touch; Capacitive_Touch_Pad
TH1301: 100k; R_0603
TP201, TP204, TP1002: TP; Pin_Header_Angled_1x01_Pitch2.54mm
TP202, TP203, TP301, TP1001: TP; Test_Point
U201: LTC4365DDB; DFN-8-1EP_2x3mm_Pitch0.5mm
U202, U1301: INA138; SOT-23-5
U301: TPS62130; QFN-16-1EP_3x3mm_Pitch0.5mm
U302, U501, U502, U1403: 74LVC1G17; SOT-353_SC-70-5
U503: PIC18F27K40T-I_ML; QFN-28-1EP_6x6mm_Pitch0.65mm
U601, U602, U603, U604: OPA340NA; SOT-23-5
U701: SSD1306; Pin_Header_Straight_1x04_Pitch2.54mm
U801, U802: AT42QT1010-TSHR; SOT-23-6
U901: ISO7321C; SOIC-8_3.9x4.9mm_Pitch1.27mm
U1001: LT6700-1-S6; TSOT-23-6
U1002: FT234XD; DFN-12-1EP_3x3mm_Pitch0.45mm
U1003, U1101, U1103, U1104, U1106, U1107, U1108, U1109: 74LVC1G06; SOT-353_SC-70-5
U1004: TPD3S014DBVR; SOT-23-6
U1102, U1105: 74LVC1G07; SOT-353_SC-70-5
U1201, U1202, U1203: LM73-1; SOT-23-6
U1302: NXQ1TXH5_101J; QFN-32-1EP_5x5mm_Pitch0.5mm
U1401, U1402: 74LVC1G14; SOT-353_SC-70-5
Y1301: 32.768kHz; Crystal_SMD_G8-2pin_3.2x1.5mm

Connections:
+5V: C205.1, C206.1, C207.1, C304.1, C305.1, C306.1, C307.1, C308.1, C401.1, C502.1, C503.1, C506.1, C507.1, C508.1, C601.1, C602.1, C603.1, C604.1, C605.1, C606.1, C609.1, C610.1, C611.1, C613.1, C614.1, C615.1, C701.1, C702.1, C703.1, C704.1, C803.1, C804.1, C805.1, C806.1, C807.1, C808.1, C901.1, C1101.1, C1102.1, C1103.1, C1104.1, C1105.1, C1106.1, C1107.1, C1108.1, C1109.1, C1201.1, C1202.1, C1203.1, C1301.1, C1302.1, C1304.1, C1323.1, C1401.1, C1402.1, C1403.1, C1404.1, C1405.1, J401.2, L301.2, L501.2, R207.1, R301.1, R306.1, R404.1, R503.1, R504.1, R601.2, R703.1, R704.1, R901.2, R902.2, R1101.1, R1102.1, R1104.1, R1105.1, R1106.1, R1108.1, R1109.1, R1110.1, R1112.1, R1113.1, R1115.1, R1116.1, R1207.1, R1208.1, R1209.1, R1210.1, R1211.1, R1212.1, R1214.1, R1303.1, R1401.2, R1402.2, SW401.1, TP301.1, U202.5, U301.14, U302.5, U501.5, U502.5, U503.17, U601.5, U602.5, U603.5, U604.5, U701.1, U801.5, U801.6, U802.5, U802.6, U901.1, U1101.5, U1102.5, U1103.5, U1104.5, U1105.5, U1106.5, U1107.5, U1108.5, U1109.5, U1201.3, U1202.3, U1203.3, U1301.3, U1301.5, U1401.5, U1402.5, U1403.5
+5VADC: C501.1, C504.1, C505.1, L501.1, U503.2
+5VP: C1307.1, C1308.1, C1310.1, C1312.1, R1301.1, R1303.2, R1308.1, R1310.1, U1301.4, U1302.15, U1302.16, U1302.25, U1302.26
+5V_USB: C902.1, C1002.1, C1003.1, C1004.1, C1005.1, C1006.1, C1008.1, R903.2, R904.2, R1001.1, R1002.1, R1005.1, R1006.1, R1009.1, TP1001.1, U901.8, U1001.5, U1002.4, U1002.9, U1003.5, U1004.4
+12V: C209.1, C301.1, C303.1, R209.2, R302.1, R606.2, TP203.1, U202.4, U301.10, U301.11, U301.12
+12Vin: C201.1, C202.1, C203.1, D201.1, J201.1, Q201.5, R201.1, R204.1, TP202.1, U201.4
/Microcontroller/PIC_I2C_SCL: R502.1, R503.2, U503.23
/Microcontroller/PIC_I2C_SDA: R501.2, R504.2, U503.22
/OLED Display/OLED_I2C_SCL: R702.1, R703.2, U701.3
/OLED Display/OLED_I2C_SDA: R701.2, R704.2, U701.4
/Temperature Sensors/Temp1_I2C_SCL: R1202.1, R1207.2, U1201.4
/Temperature Sensors/Temp1_I2C_SDA: R1201.2, R1210.2, U1201.6
/Temperature Sensors/Temp2_I2C_SCL: R1204.1, R1208.2, U1202.4
/Temperature Sensors/Temp2_I2C_SDA: R1203.2, R1211.2, U1202.6
/Temperature Sensors/Temp3_I2C_SCL: R1206.1, R1209.2, U1203.4
/Temperature Sensors/Temp3_I2C_SDA: R1205.2, R1212.2, U1203.6
/USB UART Bridge/BRIDGE_USB+: R1007.2, U1002.12
/USB UART Bridge/BRIDGE_USB-: R1008.2, U1002.1
/USB UART Bridge/CONN_USB+: C1009.1, J1001.3, R1007.1, U1004.6
/USB UART Bridge/CONN_USB-: C1010.1, J1001.2, R1008.1, U1004.5
/USB UART Bridge/POS5_USB_PGOOD: R1005.2, U1001.1, U1001.6, U1003.2
Cap_Touch_Left: R803.2, U503.6, U801.1
Cap_Touch_Right: R804.2, U503.7, U802.1
GND: C201.2, C202.2, C203.2, C204.2, C205.2, C206.2, C207.2, C208.2, C209.2, C301.2, C302.2, C303.2, C304.2, C305.2, C306.2, C307.2, C308.2, C401.2, C402.2, C502.2, C503.2, C506.2, C507.2, C508.2, C601.2, C602.2, C603.2, C604.2, C605.2, C606.2, C607.2, C608.2, C609.2, C610.2, C611.2, C612.2, C613.2, C614.2, C615.2, C616.2, C701.2, C702.2, C703.2, C704.2, C803.2, C804.2, C805.2, C806.2, C807.2, C808.2, C901.2, C1101.2, C1102.2, C1103.2, C1104.2, C1105.2, C1106.2, C1107.2, C1108.2, C1109.2, C1201.2, C1202.2, C1203.2, C1301.2, C1302.2, C1303.2, C1304.2, C1306.2, C1307.2, C1308.2, C1309.2, C1310.2, C1311.2, C1312.2, C1313.2, C1315.2, C1317.2, C1318.2, C1322.2, C1323.2, C1401.2, C1402.2, C1403.2, C1404.2, C1405.2, D201.2, J201.2, J201.3, J401.3, J701.3, J901.3, L502.2, Q401.2, R203.2, R210.2, R303.2, R305.2, R307.2, R308.2, R402.2, R505.2, R506.2, R602.1, R607.2, R1103.2, R1107.2, R1111.2, R1114.2, R1213.2, R1304.2, R1306.2, R1311.2, R1314.2, R1315.2, R1404.2, R1405.2, R1406.1, R1407.1, TH1301.2, TP201.1, TP204.1, U201.1, U201.9, U202.2, U301.6, U301.7, U301.8, U301.15, U301.16, U301.17, U302.3, U501.3, U502.3, U503.5, U503.16, U503.29, U601.2, U602.2, U603.2, U604.2, U701.2, U801.2, U802.2, U901.4, U1101.3, U1102.3, U1103.3, U1104.3, U1105.3, U1106.3, U1107.3, U1108.3, U1109.3, U1201.2, U1202.2, U1203.2, U1301.2, U1302.19, U1302.20, U1302.21, U1302.22, U1302.27, U1302.31, U1302.33, U1401.3, U1402.3, U1403.3
GNDA: C501.2, C504.2, C505.2, L502.1, U503.1
GND_USB: C902.2, C1001.2, C1002.2, C1003.2, C1004.2, C1005.2, C1006.2, C1007.2, C1008.2, C1009.2, C1010.2, C1011.2, J1001.5, L1002.1, R1004.2, TP1002.1, U901.5, U1001.2, U1002.5, U1002.13, U1003.3, U1004.2
Heartbeat_LED: R505.1, R1114.1, U501.4, U1108.2
I2C_Error_LED: R1107.1, U503.13, U1104.2
I2C_SCL: J701.2, R502.2, R702.2, R1202.2, R1204.2, R1206.2
I2C_SDA: J701.1, R501.1, R701.1, R1201.1, R1203.1, R1205.1
ICSPCLK: J401.5, U501.2, U503.24
ICSPDAT: J401.4, U502.2, U503.25
unnamed: C204.1, R208.2
unnamed: C302.1, U301.9
unnamed: C402.1, R405.2
unnamed: C801.1, U801.4
unnamed: C801.2, R801.2, R803.1, U801.3
unnamed: C802.1, U802.4
unnamed: C802.2, R802.2, R804.1, U802.3
unnamed: C1001.1, R1001.2, U1002.2
unnamed: C1007.1, U1002.3
unnamed: C1011.1, L1001.2, U1004.1, U1004.3
unnamed: C1303.1, R1301.2, R1302.1, R1305.1, R1307.1, R1309.1, U1302.9
unnamed: C1305.2, Y1301.1
unnamed: C1309.1, U1302.28
unnamed: C1313.1, R1312.2
unnamed: C1314.1, C1316.1, C1320.1, C1321.1, D1301.2, J1302.1
unnamed: C1314.2, C1316.2, C1320.2, C1321.2, R1313.1, U1302.17, U1302.18
unnamed: C1315.1, R1313.2
unnamed: C1317.1, C1319.1, R1310.2, R1311.1, U1302.10, U1302.13
unnamed: C1318.1, R1315.1, R1317.2, U1302.11
unnamed: C1319.2, R1314.1, R1316.2
unnamed: C1322.1, D1301.1, R1316.1, R1317.1
unnamed: D1001.1, U1003.4
unnamed: D1001.2, R1006.2
unnamed: D1002.2, R1009.2
unnamed: D1101.1, U1101.4
unnamed: D1101.2, R1104.2
unnamed: D1102.1, U1102.4
unnamed: D1102.2, R1105.2
unnamed: D1103.1, U1103.4
unnamed: D1103.2, R1106.2
unnamed: D1104.1, U1104.4
unnamed: D1104.2, R1109.2
unnamed: D1105.1, U1105.4
unnamed: D1105.2, R1110.2
unnamed: D1106.1, U1106.4
unnamed: D1106.2, R1112.2
unnamed: D1107.1, U1107.4
unnamed: D1107.2, R1113.2
unnamed: D1108.1, U1108.4
unnamed: D1108.2, R1115.2
unnamed: D1109.1, U1109.4
unnamed: D1109.2, R1116.2
unnamed: J1001.1, L1001.1
unnamed: J1001.6, L1002.2
unnamed: L301.1, R304.1, U301.1, U301.2, U301.3
unnamed: Q201.1, Q201.2, Q201.3, Q202.1, Q202.2, Q202.3
unnamed: Q201.4, R205.2
unnamed: Q202.4, R206.1
unnamed: Q202.5, R209.1, U201.6, U202.3
unnamed: Q401.1, R401.2, R402.1
unnamed: Q401.3, R403.2
unnamed: R201.2, R202.1, U201.3
unnamed: R202.2, R203.1, U201.2
unnamed: R204.2, U201.8
unnamed: R205.1, R206.2, R208.1, U201.5
unnamed: R302.2, R303.1, U301.13
unnamed: R304.2, R305.1, U302.2
unnamed: R306.2, R307.1, U301.5
unnamed: R401.1, SW401.2
unnamed: R403.1, R404.2, R405.1, R406.2
unnamed: R601.1, R602.2, U602.3
unnamed: R603.2, U601.1, U601.4
unnamed: R604.2, U602.1, U602.4
unnamed: R605.2, U603.1, U603.4
unnamed: R606.1, R607.1, U604.3
unnamed: R608.2, U604.1, U604.4
unnamed: R801.1, SW801.1
unnamed: R802.1, SW802.1
unnamed: R1002.2, R1003.1, U1001.3
unnamed: R1003.2, R1004.1, U1001.4
unnamed: R1213.1, U1201.1
unnamed: R1214.2, U1203.1
unnamed: R1302.2, U1302.32
unnamed: R1305.2, U1302.1
unnamed: R1307.2, U1302.2
unnamed: R1309.2, U1302.6
unnamed: R1403.2, R1404.1, U1403.2
Other_Error_LED: R506.1, R1103.1, U502.4, U1103.2
POS5_ADC: C608.1, R604.1, U503.3
POS5_PGOOD: R301.2, U301.4, U1109.2
POS5_SW_SNS: R308.1, U302.4, U503.18
POS12_ADC: C616.1, R608.1, U503.27
POS12_ISNS: C208.1, R210.1, U202.1, U601.3
POS12_ISNS_ADC: C607.1, R603.1, U503.28
POS12_PGOOD: R207.2, U201.7, U1107.2
QI_Charge: R1407.2, U503.21, U1402.4
QI_ISNS: C1306.1, R1304.1, U603.3, U1301.1
QI_ISNS_ADC: C612.1, R605.1, U503.4
QI_Idle: R1406.2, U503.20, U1401.4
QI_LED_G: R1108.2, R1402.1, U1105.2, U1302.7, U1402.2
QI_LED_R: R1102.2, R1401.1, U1102.2, U1302.8, U1401.2
QI_NTC: C1311.1, R1308.2, TH1301.1, U1302.12
QI_OSC_1: C1305.1, U1302.29
QI_OSC_2: U1302.30, Y1301.2
QI_SW: J1301.1, R1312.1, R1403.1, U1302.23, U1302.24
QI_SW_SNS: R1405.1, U503.19, U1403.4
QI_Standby: R1306.1, U503.10, U1302.14
USB_Error_LED: R1111.1, U503.14, U1106.2
USB_UART_RX: J901.1, R901.1, U503.11, U901.2
USB_UART_RX_ISO: R904.1, U901.7, U1002.7
USB_UART_TX: J901.2, R902.1, U503.12, U901.3
USB_UART_TX_ISO: R903.1, U901.6, U1002.10
~ACTIVE_LED: R1101.2, U503.15, U1101.2
~MCLR: J401.1, R406.1, U503.26
~USB_ACTIVE: D1002.1, U1002.6

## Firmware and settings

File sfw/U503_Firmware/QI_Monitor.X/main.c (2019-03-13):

/**
  Generated Main Source File

  Company:
    Microchip Technology Inc.

  File Name:
    main.c

  Summary:
    This is the main file generated using PIC10 / PIC12 / PIC16 / PIC18 MCUs

  Description:
    This header file provides implementations for driver APIs for all modules selected in the GUI.
    Generation Information :
        Product Revision  :  PIC10 / PIC12 / PIC16 / PIC18 MCUs - 1.65.2
        Device            :  PIC18F27K40
        Driver Version    :  2.00
*/

/*
    (c) 2018 Microchip Technology Inc. and its subsidiaries. 
    
    Subject to your compliance with these terms, you may use Microchip software and any 
    derivatives exclusively with Microchip products. It is your responsibility to comply with third party 
    license terms applicable to your use of third party software (including open source software) that 
    may accompany Microchip software.
    
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
    IN NO EVENT WILL MICROCHIP BE LIABLE FOR ANY INDIRECT, SPECIAL, PUNITIVE, 
    INCIDENTAL OR CONSEQUENTIAL LOSS, DAMAGE, COST OR EXPENSE OF ANY KIND 
    WHATSOEVER RELATED TO THE SOFTWARE, HOWEVER CAUSED, EVEN IF MICROCHIP 
    HAS BEEN ADVISED OF THE POSSIBILITY OR THE DAMAGES ARE FORESEEABLE. TO 
    THE FULLEST EXTENT ALLOWED BY LAW, MICROCHIP'S TOTAL LIABILITY ON ALL 
    CLAIMS IN ANY WAY RELATED TO THIS SOFTWARE WILL NOT EXCEED THE AMOUNT 
    OF FEES, IF ANY, THAT YOU HAVE PAID DIRECTLY TO MICROCHIP FOR THIS 
    SOFTWARE.
*/

#include <string.h>
#include <stdio.h>

#include "mcc_generated_files/mcc.h"

#include "pin_macros.h"
#include "terminal_control.h"
#include "heartbeat_timer.h"
#include "ring_buffer_interface.h"
#include "ring_buffer_LUT.h"
#include "cause_of_reset.h"
#include "adc_postprocessing.h"
#include "error_handling.h"
#include "LM73_I2C.h"
#include "cap_touch_int.h"
#include "NXQ_charge_state.h"
#include "oled.h"
#include "freq_meas.h"
#include "double_to_EEPROM.h"

// User IDs
#pragma config IDLOC0 = 0xD
#pragma config IDLOC1 = 0xE
#pragma config IDLOC2 = 0xA
#pragma config IDLOC3 = 0xD
#pragma config IDLOC4 = 0xB
#pragma config IDLOC5 = 0xE
#pragma config IDLOC6 = 0xE
#pragma config IDLOC7 = 0xF

/*
                         Main application
 */
void main(void)
{

    // Determine the cause of the most recent reset, save to enum
    reset_cause = getCauseOfReset();
    
    // Shine RESET LED for a little bit
    __delay_ms(250);
    
    // Initialize the device
    // These are MCC auto-generated instructions
    SYSTEM_Initialize();

    // Assign heartbeat timer handler to TMR0 ISR
    TMR0_SetInterruptHandler(heartbeatTimerHandler);

    // Assign ADC acquisitionTimerHandler to TMR2 ISR
    TMR2_SetInterruptHandler(ADC_acquisitionTimerHandler);
    
    // Call ADC callback upon ADCC interrupt
    ADCC_SetADTIInterruptHandler(ADC_PostProcessingHandler);
    
    // Assign Left Pushbutton Handler to INT1
    INT1_SetInterruptHandler(leftCapTouchHandler);
    
    // Assign Right Pushbutton Handler to INT2
    INT2_SetInterruptHandler(rightCapTouchHandler);
    
    // Assign QI Idle IOC Handler to IOC B2
    IOCBF2_SetInterruptHandler(QIIdleIOCHandler);
    
    // Assign QI Charge IOC Handler to IOC B3
    IOCBF3_SetInterruptHandler(QIChargeIOCHandler);
    
    // Assign idle /charged detection handler to TMR3 ISR
    TMR3_SetInterruptHandler(QIIdleChargedTimerHandler);
    TMR3_StopTimer();
    TMR3_Reload();
    
    // Assign error detection handler to TMR1 ISR
    TMR1_SetInterruptHandler(QIErrorTimerHandler);
    TMR1_StopTimer();
    TMR1_Reload();
    
    
    // Clear timer for QI FSW measurement
    TMR5_StopTimer();
    TMR5_WriteTimer(0);
    
    // Enable high priority global interrupts
    INTERRUPT_GlobalInterruptHighEnable();

    // Enable low priority global interrupts.
    INTERRUPT_GlobalInterruptLowEnable();
    
    // Setup virtual COM port terminal
    terminalClearScreen();
    terminalSetCursorHome();

    OLED_Init();
    OLED_Clear();
    
    // Start OLED state machine, force callback
    OLED_Frame = OLED_Boot_Frame_1;
    OLED_updateHandler();
    
    // Setup I2C temp sensors
    LM73TempSensorInitialize();
    
    // print boot message
    terminalTextAttributes(GREEN, BLACK, NORMAL);
    printf("QI Charger with Digital Monitoring\n\r"
            "Boot Complete\n\r");
    
    // Set text color based on cause of reset
    if (    reset_cause != Power_On_Reset) {
    
        terminalTextAttributes(RED, BLACK, NORMAL);
        
    }
    
    else {
    
        terminalTextAttributes(GREEN, BLACK, NORMAL);
        
    }
    
    // Print cause of reset
    printf("Cause of most recent device reset was: %s\n\r", getCauseOfResetString(reset_cause));

    terminalTextAttributes(GREEN, BLACK, NORMAL);    
    // Enable QI power conversion
    QI_STANDBY_PIN = 0;
    printf("QI Wireless Power Conversion Enabled\n\r");

    terminalTextAttributes(YELLOW, BLACK, NORMAL);
    printf("\n\rHelp messages and neutral responses appear in yellow\n\r");
    terminalTextAttributes(GREEN, BLACK, NORMAL);
    printf("System parameters and affirmative responses appear in green\n\r");
    terminalTextAttributes(CYAN, BLACK, NORMAL);
    printf("Measurement responses appear in cyan\n\r");
    terminalTextAttributes(RED, BLACK, NORMAL);
    printf("Errors and negative responses appear in red\n\r");
    terminalTextAttributesReset();
    printf("User input appears in white\n\r");
    terminalTextAttributes(YELLOW, BLACK, NORMAL);
    printf("\n\rCall 'Help' for list of supported commands\n\r");

    // Reset virtual COM port text attributes
    terminalTextAttributesReset();
    
    // See if we're starting idle or fully charged
    if (QI_CHARGE_PIN == 0 && QI_IDLE_PIN == 0) nxq_charge_state = QI_Idle;
    else if (QI_CHARGE_PIN == 1 && QI_IDLE_PIN == 1) nxq_charge_state = QI_Fully_Charged;
    
    // Get starting data
    LM73AcquisitionHandler();
    freqMeasStartCaptures();
    
    // Recover saved variables from NVM
    recoverEEPROMToRAM();
    
    // Endless loop
    while (1) {
        
        // If received terminal data is ready, process it
        if (eusart2RxStringReady) terminal_ringBufferPull();
        
        // If the OLED needs to be updated, update it
        if (OLED_update_flag) OLED_updateHandler();
        
        // If new LM73 data is requested, get it
        if (LM73_start_flag) LM73AcquisitionHandler();
        
        // If we need to start a new freq meas capture, start it
        if (freq_meas_start_flag) freqMeasStartCaptures();
        
        // If we need to print out live data to the terminal, do it.
        if (live_measurement_request_flag) {
         
            live_measurement_request_flag = 0;
            
            // terminalClearScreen();
            terminalSetCursorHome();
            
            terminalTextAttributes(GREEN, BLACK, BOLD);
            printf("Live Measurements:\033[K\n\r\033[K\n\r");
            
            printCurrentMeasurements();
            
            terminalTextAttributes(YELLOW, BLACK, BOLD);
            printf("Press enter key to exit\033[K\n\r\033[K\n\r");
            terminalTextAttributesReset();
            
        }
        
        // Update error LEDs based on error handler state
        updateErrorLEDs();
        
        // Check for new min and max measurements to save off
        updataMinMaxRAMAliases();
        
        if (nvm_update_flag) writeEEPROMFromRAM();
        
    }
}
/**
 End of File
*/

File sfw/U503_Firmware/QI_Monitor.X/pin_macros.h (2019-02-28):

/* Microchip Technology Inc. and its subsidiaries.  You may use this software 
 * and any derivatives exclusively with Microchip products. 
 * 
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
 * IN NO EVENT WILL MICROCHIP BE LIABLE FOR ANY INDIRECT, SPECIAL, PUNITIVE, 
 * INCIDENTAL OR CONSEQUENTIAL LOSS, DAMAGE, COST OR EXPENSE OF ANY KIND 
 * WHATSOEVER RELATED TO THE SOFTWARE, HOWEVER CAUSED, EVEN IF MICROCHIP HAS 
 * BEEN ADVISED OF THE POSSIBILITY OR THE DAMAGES ARE FORESEEABLE.  TO THE 
 * FULLEST EXTENT ALLOWED BY LAW, MICROCHIP'S TOTAL LIABILITY ON ALL CLAIMS 
 * IN ANY WAY RELATED TO THIS SOFTWARE WILL NOT EXCEED THE AMOUNT OF FEES, IF 
 * ANY, THAT YOU HAVE PAID DIRECTLY TO MICROCHIP FOR THIS SOFTWARE.
 *
 * MICROCHIP PROVIDES THIS SOFTWARE CONDITIONALLY UPON YOUR ACCEPTANCE OF THESE 
 * TERMS. 
 */

/* 
 * File:   
 * Author: 
 * Comments:
 * Revision history: 
 */

// This is a guard condition so that contents of this file are not included
// more than once.  
#ifndef _PIN_MACROS_H
#define	_PIN_MACROS_H

#include <xc.h> // include processor files - each processor file is guarded.  

// These are pin macro definitions so that microcontroller I/O can be easily
// accessed instead of reading from/writing to bitfields in registers

// Port A
#define POS12_ADC_PIN           PORTAbits.RA0
#define POS12_ISNS_ADC_PIN      PORTAbits.RA1
#define POS5_ADC_PIN            PORTAbits.RA4
#define QI_ISNS_ADC_PIN         PORTAbits.RA5
#define CAP_TOUCH_RIGHT_PIN     PORTAbits.RA6
#define CAP_TOUCH_LECT_PIN      PORTAbits.RA7

// Port B
#define POS5_SW_SNS_PIN         PORTBbits.RB0
#define QI_SW_SNS_PIN           PORTBbits.RB1
#define QI_IDLE_PIN             PORTBbits.RB2
#define QI_IDLE_PIN_RISE        IOCBPbits.IOCBP2
#define QI_IDLE_PIN_FALL        IOCBNbits.IOCBN2
#define QI_CHARGE_PIN           PORTBbits.RB3
#define QI_CHARGE_PIN_RISE      IOCBPbits.IOCBP3
#define QI_CHARGE_PIN_FALL      IOCBNbits.IOCBN3
#define HEARTBEAT_LED_PIN       LATBbits.LATB6
#define OTHER_ERROR_LED_PIN     LATBbits.LATB7

// Port C
#define QI_STANDBY_PIN          LATCbits.LATC2
#define I2C_ERROR_LED_PIN       LATCbits.LATC5
#define USB_ERROR_LED_PIN       LATCbits.LATC6
#define nACTIVE_LED_PIN         LATCbits.LATC7


#endif	/* _PIN_MACROS_H */

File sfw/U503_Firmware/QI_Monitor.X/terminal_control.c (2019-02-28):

#include <xc.h>
#include <stdio.h>
#include <string.h>
#include <stdint.h>

#include "terminal_control.h"
// #include "usb_uart.h"


// This function clears the terminal
void terminalClearScreen(void) {
    printf("\033[2J");
}

// This function moves the terminal cursor to top left corner
void terminalSetCursorHome(void) {
    printf("\033[H");
}

// This function clears the line the cursor is currently at on the terminal
void terminalClearLine(void) {
    printf("\033[K");
}

// This function saves the current cursor position on the terminal
void terminalSaveCursor(void) {
    printf("\033[s");
}

// This function returns the cursor to saved position on terminal
void terminalReturnCursor(void) {
    printf("\033[u");
}

// Text attributes function
// See attributes enums in "USB_UART.h"
// Call like so:
/*

    USB_UART_textAttributes(<TEXT COLOR (ALL CAPS)>, 
                            <BACKGROUND COLOR (ALL CAPS)>, 
                            <TEXT EFFECT (ALL CAPS)>);

*/

void terminalTextAttributes(text_color_t foreground_color,
        text_color_t background_color,
        text_attribute_t input_attribute) {
    
    char print_string[16];
    
    // Null print string
    uint8_t i;
    for (i = 0; i < sizeof(print_string); i++) {
     
        print_string[i] = '\0';
        
    }
    
    strncpy(print_string, "\033[", sizeof(print_string));
    
    switch (input_attribute) {
     
        case NORMAL:
            strcat(print_string,"0");
            break;
        case BOLD:
            strcat(print_string,"1");
            break;
        case UNDERSCORE:
            strcat(print_string,"4");
            break;
        case BLINK:
            strcat(print_string,"5");
            break;
        case REVERSE:
            strcat(print_string,"7");
            break;
        case CONCEALED:
            strcat(print_string,"8");
            break;

        default:
            strcat(print_string,"0");
            break;
    }
    
    strcat(print_string,";");
    
    switch (foreground_color) {
     
        case BLACK:
            strcat(print_string,"30");
            break;
        case RED:
            strcat(print_string,"31");
            break;
        case GREEN:
            strcat(print_string,"32");
            break;
        case YELLOW:
            strcat(print_string,"33");
            break;
        case BLUE:
            strcat(print_string,"34");
            break;
        case MAGENTA:
            strcat(print_string,"35");
            break;
        case CYAN:
            strcat(print_string,"36");
            break;
        case WHITE:
            strcat(print_string,"37");
            break;
            
        default:
            strcat(print_string,"37");
            break;
    }
    
    strcat(print_string,";");
    
    switch (background_color) {
     
        case BLACK:
            strcat(print_string,"40");
            break;
        case RED:
            strcat(print_string,"41");
            break;
        case GREEN:
            strcat(print_string,"42");
            break;
        case YELLOW:
            strcat(print_string,"43");
            break;
        case BLUE:
            strcat(print_string,"44");
            break;
        case MAGENTA:
            strcat(print_string,"45");
            break;
        case CYAN:
            strcat(print_string,"46");
            break;
        case WHITE:
            strcat(print_string,"47");
            break;
            
        default:
            strcat(print_string,"40");
            break;
    }
    
    strcat(print_string,"m");
    
    printf(print_string);
    
}

// Reset text attributes to white text, black background, no effects
void terminalTextAttributesReset(void) {
 
    // USB_UART_textAttributes(WHITE, BLACK, NORMAL);
    printf("\033[0;37;40m");
    
}

// tests all the function written for this example
void terminalPrintTestMessage(void) {
    
    // Set starting text color white, background black, no fancy stuff
    // Print COM port settings
    terminalTextAttributesReset();
    terminalClearScreen();
    terminalSetCursorHome();
    printf("USB UART Test\n\r\n\r");
//    printf("COM Port Settings:\n\r");
//    printf("    Baud Rate: %s\n\r", USB_UART_BAUD_RATE_STR);
//    printf("    Data Length: %s\n\r", USB_UART_DATA_LENGTH_STR);
//    printf("    Parity: %\n\r", USB_UART_PARITY_STR);
//    printf("    Stop Bits: %s\n\r", USB_UART_STOP_BITS_STR);
//    printf("    Flow Control: %s\n\r\n\r", USB_UART_FLOW_CONTROL_STR);
//        
    // Test text attributes
    printf("Testing text attributes:\n\r");

    // Print some black text
    terminalTextAttributesReset();
    terminalTextAttributes(BLACK, WHITE, NORMAL);
    printf("This text is black\n\r");

    terminalTextAttributesReset();
    terminalTextAttributes(RED, BLACK, NORMAL);
    printf("This text is red\n\r");

    terminalTextAttributesReset();
    terminalTextAttributes(GREEN, BLACK, NORMAL);
    printf("This text is green\n\r");

    terminalTextAttributesReset();
    terminalTextAttributes(YELLOW, BLACK, NORMAL);
    printf("This text is yellow\n\r");

    terminalTextAttributesReset();
    terminalTextAttributes(BLUE, WHITE, NORMAL);
    printf("This text is blue\n\r");

    terminalTextAttributesReset();
    terminalTextAttributes(MAGENTA, BLACK, NORMAL);
    printf("This text is magenta\n\r");

    terminalTextAttributesReset();
    terminalTextAttributes(CYAN, BLACK, NORMAL);
    printf("This text is cyan\n\r");
    
    terminalTextAttributesReset();
    terminalTextAttributes(WHITE, BLACK, NORMAL);
    printf("This text has a black background\n\r");
    
    terminalTextAttributesReset();
    terminalTextAttributes(BLACK, RED, NORMAL);
    printf("This text has a red background\n\r");

    terminalTextAttributesReset();
    terminalTextAttributes(BLACK, GREEN, NORMAL);
    printf("This text has a green background\n\r");
    
    terminalTextAttributesReset();
    terminalTextAttributes(BLACK, YELLOW, NORMAL);
    printf("This text has a yellow background\n\r");
    
    terminalTextAttributesReset();
    terminalTextAttributes(WHITE, BLUE, NORMAL);
    printf("This text has a blue background\n\r");
    
    terminalTextAttributesReset();
    terminalTextAttributes(BLACK, MAGENTA, NORMAL);
    printf("This text has a magenta background\n\r");
    
    terminalTextAttributesReset();
    terminalTextAttributes(BLACK, CYAN, NORMAL);
    printf("This text has a cyan background\n\r");
    
    terminalTextAttributesReset();
    terminalTextAttributes(BLACK, WHITE, NORMAL);
    printf("This text has a white background\n\r");
    
    terminalTextAttributesReset();
    terminalTextAttributes(WHITE, BLACK, BOLD);
    printf("This text is bold\n\r");

    terminalTextAttributesReset();
    terminalTextAttributes(WHITE, BLACK, UNDERSCORE);
    printf("This text is underscored\n\r");
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

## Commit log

2018-12-21 Added blank KiCad Project
    [QI_Charger.kicad_pcb, QI_Charger.sch]
2018-12-21 Added a few sheets
    [Microcontroller.sch, Microcontroller_Programming.sch, POS12_Input.sch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]
2018-12-21 Copied in USB sheet from earlier project
    [Microcontroller.sch, Microcontroller_Programming.sch, POS12_Input.sch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]
2018-12-21 Pulled in some status LEDs from previous project
    [Microcontroller.sch, Microcontroller_Programming.sch, OLED_Display.sch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]
2018-12-21 Changed all POS3P3 voltages to POS5
    [Microcontroller_Programming.sch, OLED_Display.sch, Status_LEDs_1.sch]
2018-12-21 Added microcontroller
    [Microcontroller.sch, Microcontroller_Programming.sch, OLED_Display.sch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]
2018-12-21 Added more to microcontroller and other sheets
    [Microcontroller.sch, Microcontroller_Programming.sch, OLED_Display.sch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]
2018-12-22 Added QI charge controller, some passives
    [Microcontroller.sch, Microcontroller_Programming.sch, OLED_Display.sch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]
2018-12-23 Added parts to QI controller page
    [Bluetooth.sch, Microcontroller.sch, Microcontroller_Programming.sch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]
2018-12-23 Added some QI interface circuitry
    [Bluetooth.sch, QI_Controller.sch, QI_Interface.sch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]
2018-12-27 Pulled in power input sheet from other project
    [Microcontroller.sch, Microcontroller_Programming.sch, OLED_Display.sch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]
2018-12-27 Added ADC and current sensing circuits
    [ADC_Drivers.sch, Microcontroller.sch, Microcontroller_Programming.sch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]
2018-12-28 Added a bunch of stuff to schematic
    [ADC_Drivers.sch, Microcontroller.sch, Microcontroller_Programming.sch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]
2018-12-28 Added cap touch sensors
    [ADC_Drivers.sch, Capacitive_Touch_Sensors.sch, Microcontroller.sch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]
2019-01-04 Pretty much finished schematic besides mounting holes
    [ADC_Drivers.sch, Capacitive_Touch_Sensors.sch, Mechanical.sch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]
2019-01-07 Pulled in parts to PCB
    [QI_Charger.kicad_pcb, QI_Controller.sch]
2019-01-07 Fixed some footprint issues
    [ADC_Drivers.sch, POS12_Input.sch, POS5_Power_Supply.sch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]
2019-01-07 Arranged a lot of parts on PCB
    [QI_Charger.kicad_pcb]
2019-01-07 Placed more parts
    [Microcontroller_Programming.sch, QI_Charger.kicad_pcb]
2019-01-08 Added test points, arranged more parts on PCB
    [POS12_Input.sch, POS5_Power_Supply.sch, QI_Charger.kicad_pcb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]
2019-01-09 Added mounting holes, board outline
    [Mechanical.sch, QI_Charger.kicad_pcb]
2019-01-09 Finished initial placement of parts
    [Microcontroller.sch, QI_Charger.kicad_pcb, QI_Controller.sch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]
2019-01-09 rearranged some parts, got rid of PIC crystal
    [Microcontroller.sch, QI_Charger.kicad_pcb]
2019-01-09 Added design rules, layer setup
    [QI_Charger.kicad_pcb]
2019-01-09 Started routing
    [QI_Charger.kicad_pcb]
2019-01-09 More routing
    [QI_Charger.kicad_pcb]
2019-01-10 Finished routing
    [QI_Charger.kicad_pcb]
2019-01-11 Added BOM
    [QI_Charger_bom_A.xlsx]
2019-01-14 Added communications test points
    [OLED_Display.sch, QI_Charger.kicad_pcb, USB_UART_Isolation.sch]
2019-01-15 Added a bunch of graphical items to PCB
    [POS12_Input.sch, QI_Charger.kicad_pcb]
2019-02-06 BOM changes, gitignore
    [QI_Charger.kicad_pcb, QI_Charger_bom_A.xlsx, Status_LEDs_1.sch]
2019-02-06 Added main and interrupt manager files
2019-02-14 Added pin macros and terminal control
    [QI_Charger_bom_A.xlsx]
2019-02-15 Added more auto-generated code
    [QI_Charger_bom_A.xlsx]
2019-02-20 Added LOTs of firmware features, got the board working
2019-02-20 Fixed a few serial commands for clarity
    [main.c, ring_buffer_LUT.c]
2019-02-21 Added ADC firmware, temp and current sensors aren't working
2019-02-23 Added lots of ADC and calculation features
2019-02-23 Added die temp offset hack
2019-02-24 Added extensive error handling, I2C temp sensor stuff
    [Temperature_Sensors.sch]
2019-02-24 Trying to fix heartbeat glitch
    [adc_postprocessing.c, error_handling.c, heartbeat_timer.c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]
2019-02-25 Added QI charge state detection, return to Idle not working
    [main.c, pin_macros.h]
2019-02-27 Added TMR6 to return nxq_charge_state to Idle, now it won't set to charging afterward
    [main.c, ring_buffer_LUT.c]
2019-02-27 Idle and charging work, error does not
2019-02-28 Got LM73 temp sensors working
2019-02-28 Got OLED working and full charge detection
2019-02-28 Got OLED menus working, now LM73s are broken
    [LM73_I2C.c, oled.h]
2019-03-01 Fixed charge detect bug, added OLED frames
    [oled.c, oled.h]
2019-03-09 Fixed FSW serial commands
    [ring_buffer_LUT.c]
2019-03-10 Got charge error detection fixed
    [main.c]
2019-03-10 Added QI charge time measurement
2019-03-11 Added output charge and energy measurements
2019-03-13 Cleaned up schematic
    [ADC_Drivers.sch, Capacitive_Touch_Sensors.sch, Mechanical.sch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]
2019-03-13 Removed extra hdw files
    [Source_Selection.sch, USB.sch]
2019-03-13 Removed more extra hdw files
    [USB_Power_Input.sch]

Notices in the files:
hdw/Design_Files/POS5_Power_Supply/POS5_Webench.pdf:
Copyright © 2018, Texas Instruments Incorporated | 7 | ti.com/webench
